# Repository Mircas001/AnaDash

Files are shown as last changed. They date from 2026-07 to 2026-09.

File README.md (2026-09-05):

# AnaDash - Resource monitor + macropad 
**THIS IS WIP! NOT TESTED YET!**
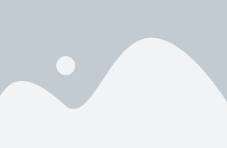
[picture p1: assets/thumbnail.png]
Thumbnail


This is an resource monitor for your PC, also featuring an macropad, inspired by Alex Bailey's system monitor and Hack Club's hackpad program! It allows you to take a quick glance and see your system information, while keeping the screen free for anything you do!
This was made after watching Alex Bailey's very silly cpu monitor video!, I've been wanting to make it for 2 years now! I also added an hackpad after seeing the very helpful Hack Club Hackpad program's guides

## Features:
- 4x Analog Gauges showing CPU usage, CPU temperature, RAM usage and Swap usage, driven by an MCP4728 chip!
- 8x Cherry MX keys for any macro your heart wishes!
- An LCD display that can show time, notifications and current song!
- An rotary encoder for changing your volume! Including a switch for mute!

## Case
AnaDash consists of embedded-rust-rp2040 parts, each one split into 
- An case, that supports it and holds it, also houses the raspberry, this part is split in two as it's too big to fit in most printers!
 
- An front plate, that you insert heatset inserts into and then screw the parts in, also split in two!
- An front case, which hides all the PCBs and wiring and gives a nice flush finish, split in two as well!
- An encoder, not split in two, with regular rectangular extruding parts for better grip while also keeping printability!

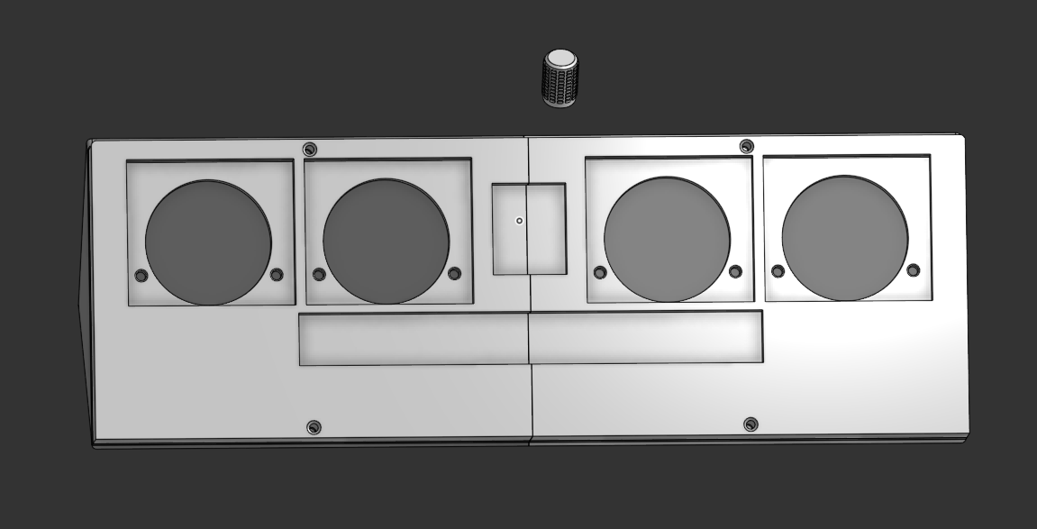
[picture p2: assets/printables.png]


Since the parts are split in two, you'll have to weld them, use an cheap soldering iron or preferentially an plastic welder for this job, since it can damage soldering tips. I can also help you make an version where both parts are one in case you want to print them as one part.

The design files are available [here](https://cad.onshape.com/documents/ea3d35dc7a38396ad80a61d7/w/835ea08936cef2d122cf7568/e/898c0cf3f941f1983e6f2559)

## PCB
This project was designed in KiCad, it uses a pair of 2 layer PCBs, the PCBs were split because the switches had to be at an angle while the pico had to sit straight.
For this to work, you must connect the following, all of the cables are JST-XH, as it features an locking mechanism.
You must make the following connections: (Pinouts are in left to right, when viewed from abovee!, GND will always be the rounded rectangle!) 
- DisplayConnector (BL, SCK, SDA, CS, RESET, CS, VCC, GND) - connect this to the matching pins on the display.
- LeftKeyConnector (Switch1, Switch2, Switch3, Switch4, GND) - The Input Board has matching connections!
- RightKeyConnector (Switch5, Switch6, Switch7, Switch8, GND) - The Input Board has matching connections!
- EncoderConnector (B, A, Switch, GND) - The Input Board has matching connections!

### Main PCB
This Board features the Pico, the DAC, the outputs for the ammeters, the display connector and the connections to the input board.            
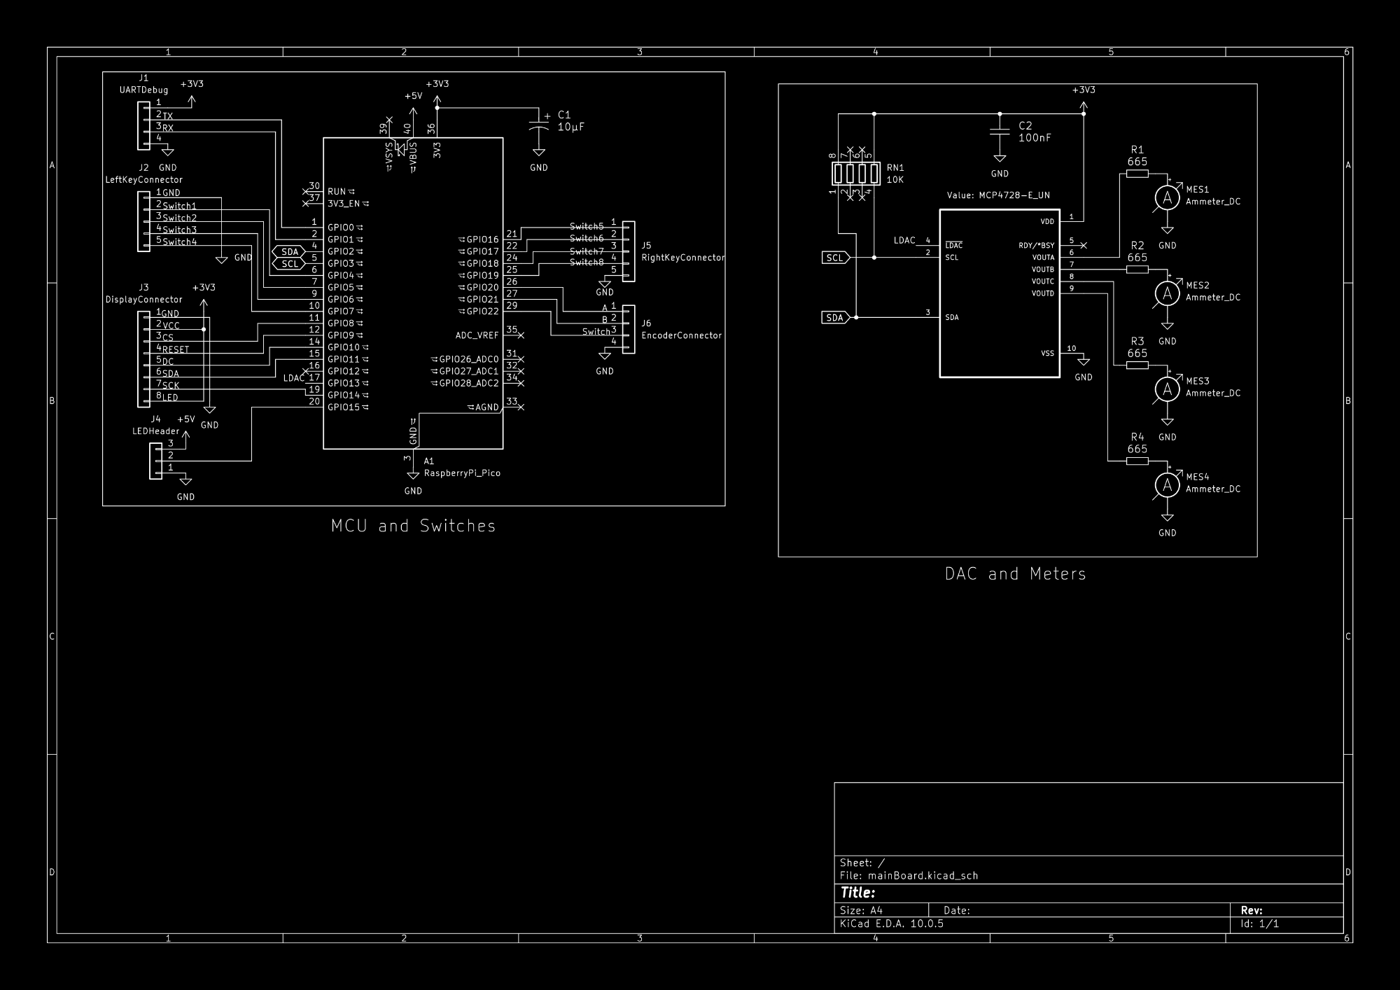
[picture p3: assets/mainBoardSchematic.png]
Schematic

[You can check out the PCB and schematic on KiCanvas!](https://kicanvas.org/?repo=https%3A%2F%2Fgithub.com%2FMircas001%2FAnaDash%2Ftree%2Fmain%2Fhardware%2FmainBoard)                                            
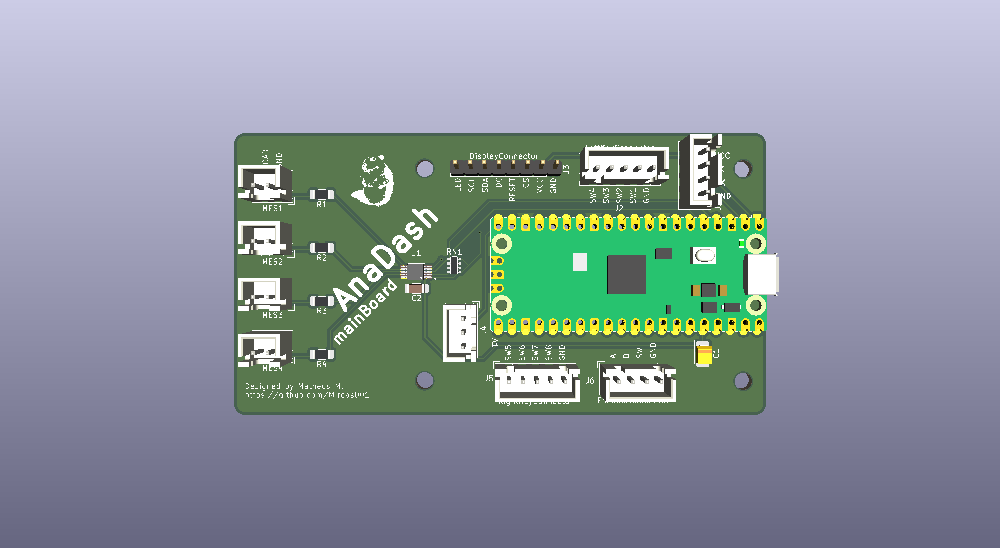
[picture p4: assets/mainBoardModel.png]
3D Model


### Input PCB
This PCB has all the keys and the encoder and serves to take inputs, it is angled together with the display and gauges at 45 degrees for ergonomics!                 
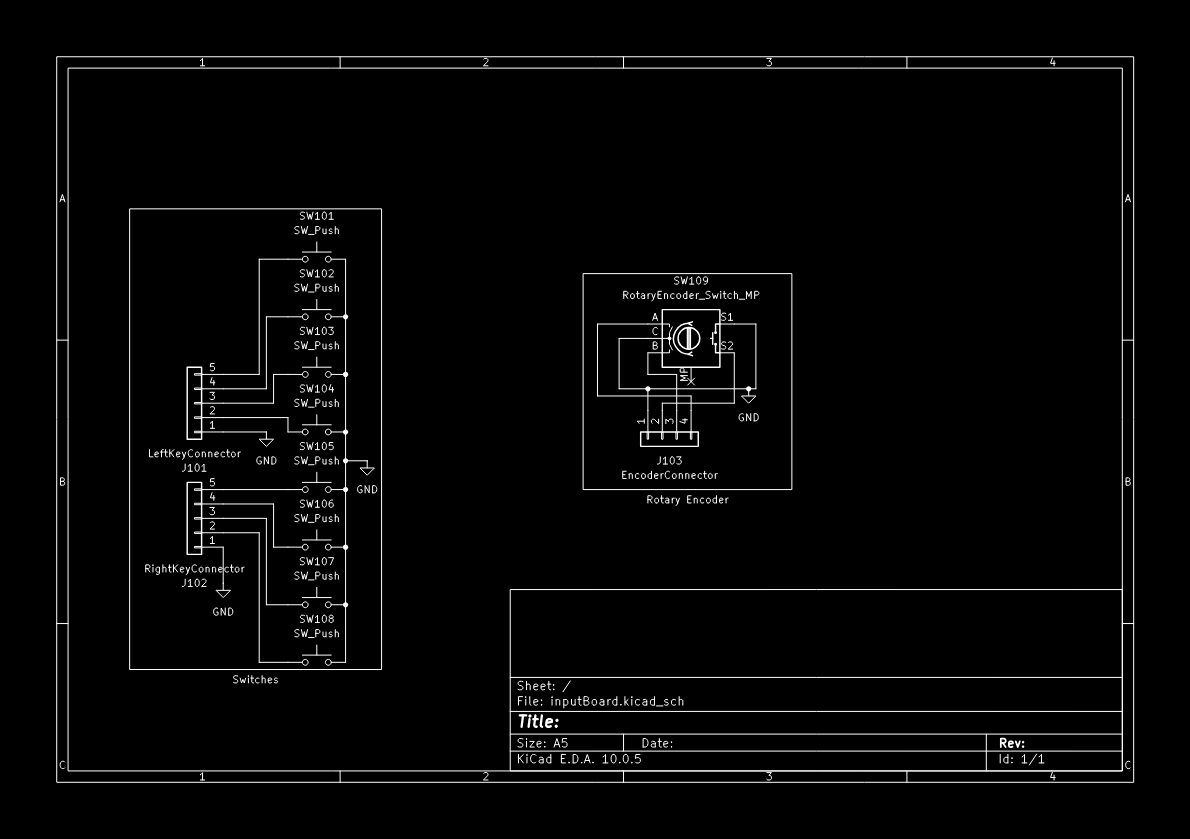
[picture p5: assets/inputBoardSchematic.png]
Schematic

[You can check out the PCB and schematic on KiCanvas!](https://kicanvas.org/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)                                         
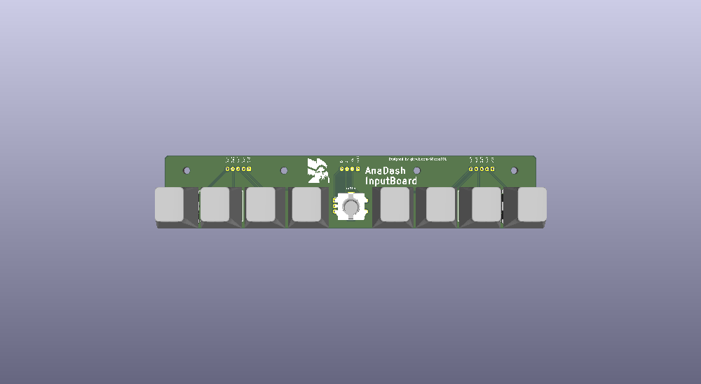
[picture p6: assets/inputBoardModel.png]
3D Model


## Software
The software has been done entirely in rust, it's memory safe, professional, and has great performance!

Before setting up the software, you'll need to install these programs!
- [rustup](https://rustup.rs) - this is the rust toolchain, and it's the recommended way to compile rust code!
- [probe-rs](https://probe.rs) - **ONLY IF** you are gonna upload via an **debug probe**.
- [picotool](https://github.com/raspberrypi/pico-sdk-tools/releases) - **ONLY IF** you are gonna upload via **USB**.
- [lm-sensors](https://github.com/lm-sensors/lm-sensors) - This provides the sensors the driver can read from! Make sure to set it up before!

It's consisted in 3 parts:
- Firmware: Runs the Pico!
- Driver: Gets the info from your PC!
- Shared library: This is so both firmware and hardware agree with each other!

### Firmware
This firmware supports the Raspberry Pi Pico 1!
There are two ways you can upload it to the pico:

#### Upload via debug probe
For this, you need to connect your debug probe to SWD port!
```bash
git clone https://github.com/Mircas001/AnaDash.git
cd AnaDash/software/firmware
cargo run --release
```

#### Upload via USB
For this, all you need to do is connect the Raspberry Pi Pico to your computer via USB, and run with the usb-deploy feature!
```bash
git clone https://github.com/Mircas001/AnaDash.git
cd AnaDash/software/firmware
cargo run -F usb-deploy --release 
```

### Drivers
This only supports Linux for now! But I can answer questions about the code to help anyone who wants to port it! It works as a systemd service that uses udev rules to start as soon as you plug it in!

#### PKGBUILD method
If you run Arch Linux or any other Arch Based distro, you can use this to install! For now you have to manually install the PKGBUILD, but it'll get uploaded to the AUR once it's done!
**This is the recommended method.**
```bash 
git clone https://github.com/Mircas001/anadash-driver.git
cd anadash-driver
makepkg -si
```

#### Compile it yourself
This is more complicated! But it should work!
1. Make sure you are in the dialout group to get serial perms!
```bash
sudo usermod -aG dialout $USER
```
2. Install all the files!
```bash
git clone https://github.com/Mircas001/AnaDash.git
cd AnaDash/software/driver
cargo build --release
sudo cp target/release/anadash-driver /usr/local/bin
sudo chmod 755 /usr/local/bin/anadash-driver 
sudo cp anadash-driver@.service /etc/systemd/system
sudo cp 99-anadash.rules /etc/udev/rules.d
```
3. Reload everything!
```bash 
sudo systemctl daemon-reload
sudo udevadm control --reload-rules
sudo udevadm trigger
```
It should work as soon as you plug in the device!

You're also always welcome to implement these steps in an package file, so other people with your distro have it easier!

### Troubleshooting the drivers
Since it's an systemd service, you can get the logs like this, replacing ```<serialport>``` with the device's serial port! Usually, it's ttyUSB0.
```bash
systemctl status anadash-driver@<serialport>.service
journalctl -u anadash-driver@<serialport>.service
```

## Assembly  
See [assembly.md](https://github.com/Mircas001/AnaDash/blob/main/ASSEMBLY.md)

## Usage
After installation of drivers, assembly, and flashing, the project SHOULD be plug and play. The macropad uses F13-F21, so to setup the macros, just use plug those keys in whatever software you want!  

## Debugging the device
There is an UART port at the main board for debugging!
Also, there are also some key combinations baked in the firmware:
- You can press the 1st key and the 8th key (the two outhermost keys) to reset the pico!
- You can press the 4th key and the 5th key (the two innermost keys) to go into DFU mode!

## Miscellaneous note
You will need to print the labels for the meters in A4 sticker paper, if you are an manufacturer, you should get it custom printed!                           
The labels are available here: [Labels](https://raw.githubusercontent.com/Mircas001/AnaDash/refs/heads/main/production/meterLabels.svg)

There is an LED header added to the PCB, however, I did not implement the code for it, it is there for future use! You are also free to repurpose it!

## BOM
| Designator | Qty |
| --- | --- |
| 1.77inch ST7735 Display | 1 |
| 85C1 Ammeter 5mA | 4 |
| FIXME SCREWS | 1 |
| M3 X 4.2 X L4.0 Brass Heatset Insert 100pcs | 1 |
| M2 X 3.2 X L4.0 Brass Heatset Insert 100pcs | 1 |
| Countersunk M3x8mm screw | 12  |
| Countersunk M3x20mm screw | 4 |
| Panhead M2x8mm screw | 4 |
| Panhead M3x8mm screw | 4 |
| Cherry MX Compatible Switches 10pcs | 8 |
| XDA2 1U Keycaps 10pcs | 1 |
| EC11 Rotary Encoder 20mm with Switch | 1 |
| JST-XH Kit | 1 |
| Raspberry Pi Pico | 1 |
| MCP4728-E | 1 |
| 10uF Tantalum Capacitor 1206 | 1 |
| 100nF Ceramic Capacitor 1206 | 1 |
| 10KΩ 4x0603 Concave Resistor Network | 1 |
| 665Ω Resistor | 4 |
| Main Board at JLCPCB  (PCBA) | 1 | 
| Input board at JLCPCB | 1 |
| 3D Printed parts | 7 | 

Details, such as aliexpress links, LCSC part numbers and cost (as of June 2026) are available here: [BOM](https://github.com/Mircas001/AnaDash/blob/main/production/BOM.csv)

It is strongly recommended

You can also get the JLCPCB BOM for the main board (in case you want to get PCBA) here: [BOM](https://github.com/Mircas001/AnaDash/blob/main/production/mainBoard/jlcpcb_bom.csv)

However, if you do get PCBA, it's recommended to only request the soldering of SMD components, as it's cheaper this way! Also, the 665ohm resistors need to be manually filled in, apparently they're so new there's not even a footprint for it! But I believe this issue will go away with time.         

The input board does not feature an JLCPCB BOM for PCBA because they do not have the parts for it! However, I have left the netlist and positions there in case you have an pick and place machine, but official support for assembling it this way is NOT provided! It's recommended to hand solder instead! Only THD components are used there.

## Software used:
This project was designed in:
- [KiCad for the PCBs!](https://www.kicad.org)
- [Visual Studio Code for the software!](https://code.visualstudio.com/)
- [Onshape for the 3D design!](https://onshape.com/)

## TODO List:
- [X] Design the main PCB 
- [X] Design the input PCB
- [X] Design the meters
- [X] Make the drivers
- [X] Make the driver into an actual driver
- [X] Make the firmware
- [ ] Make the Case

## Credits
- [Lex Bailey, for giving me the inspiration to start this project a few years ago, and for help with the meter labels](https://www.youtube.com/watch?v=4J-DTbZlJ5I)
- [Hack Club Macondo program, for the funding](https://macondo.hackclub.com/)
- [OrpheusPad, for serving as reference as to how should the git repo and README look like](https://github.com/qcoral/orpheuspad/tree/main)
- [HackPad program, which, despite not participating in it, guided me through PCB design](https://hackpad.hackclub.com/)
- [CarlKCarlK's clock project which I'm using as inspiration for parts of the codecode](https://github.com/CarlKCarlK/clock)
- [Siliconwit's guide on embassy-usb](https://siliconwit.com/education/embedded-rust-rp2040/usb-device-embassy/)

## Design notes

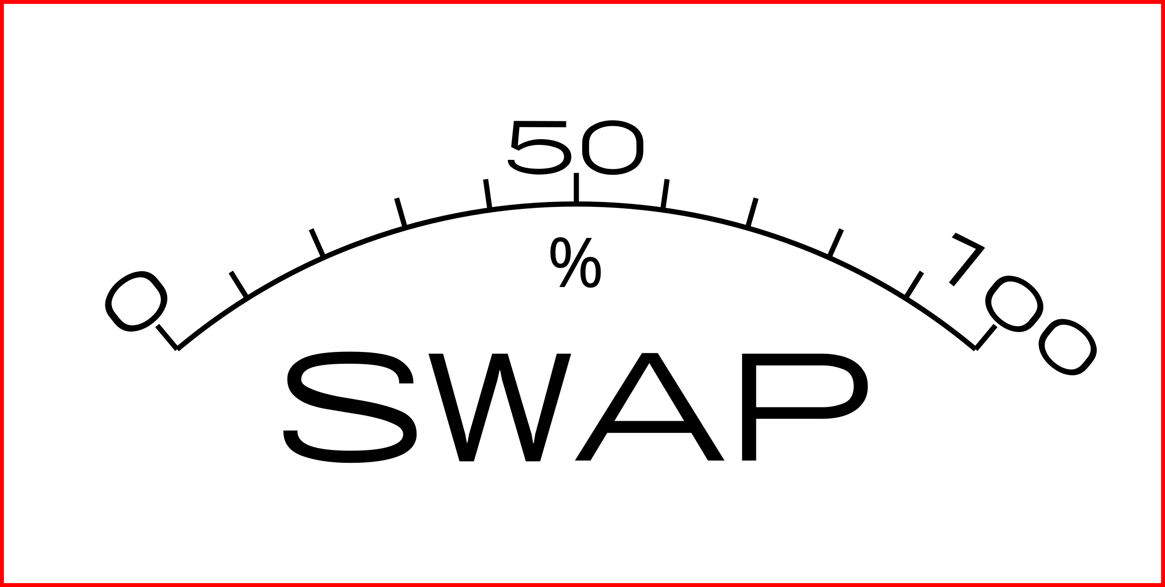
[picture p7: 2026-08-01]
hardware/case/assets/meterLabels_g7.png

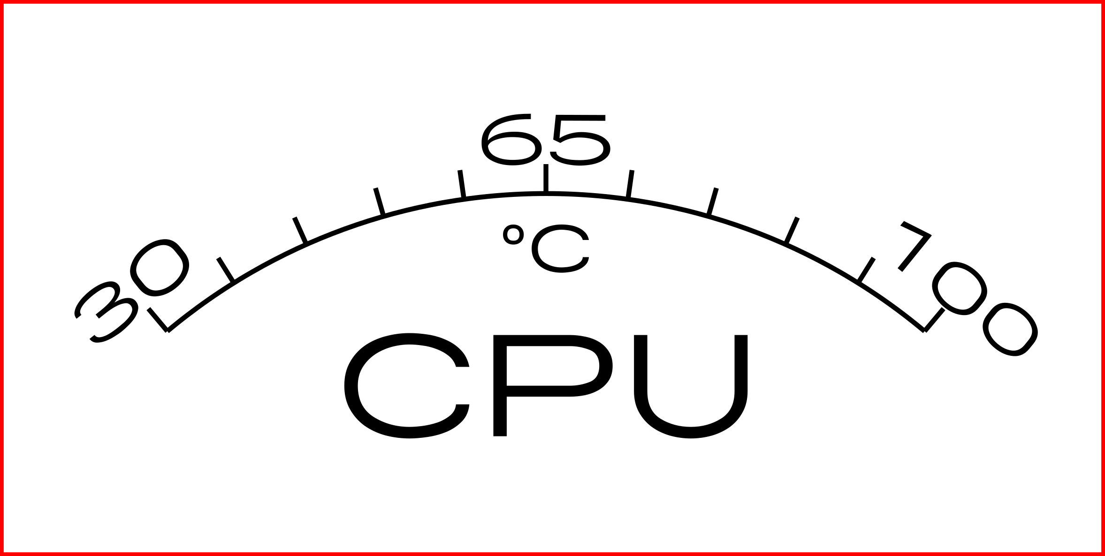
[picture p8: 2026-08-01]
hardware/case/assets/meterLabels_g4.png

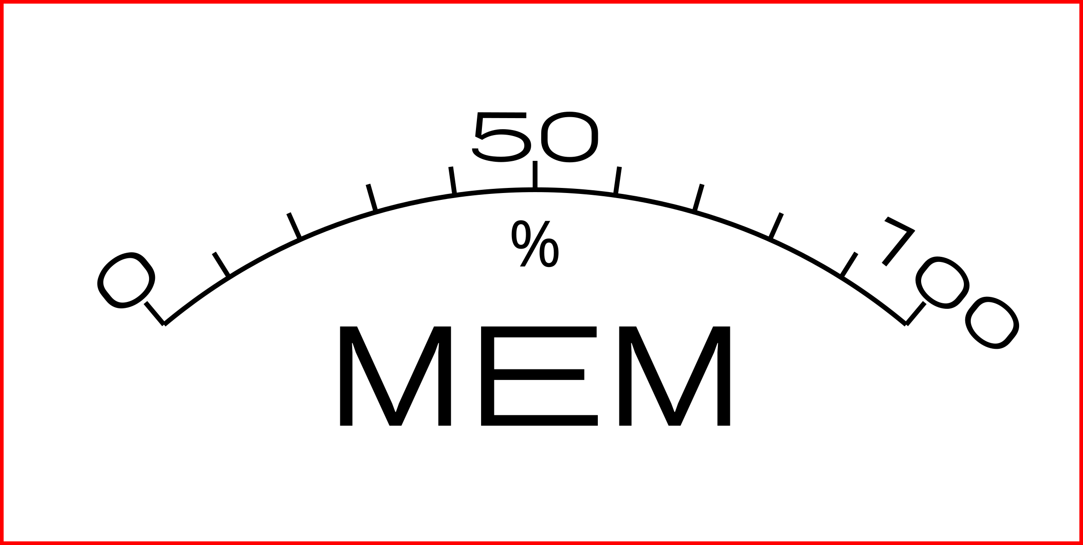
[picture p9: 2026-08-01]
hardware/case/assets/meterLabels_g2.png

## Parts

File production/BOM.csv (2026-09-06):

Designator | Qty | SMD/THT? | PCB | LCSC Part # | AliExpress Link | Price (Aliexpress Old User) | Price (Aliexpress New User)
1.77inch ST7735 Display | 1 | N/A | None | C5329585 | https://pt.aliexpress.com/item/1005003112573376.html | 2.63 | 1.60
85C1 Ammeter 5mA | 4 | N/A | None | - | https://pt.aliexpress.com/item/1005005650153387.html | 14.40 | 14.88
M3 X 4.2 X L4.0 Brass Heatset Insert 100pcs | 1 | N/A | None | - | https://pt.aliexpress.com/item/1005006838108683.html | 1.38 | 3.31
M2 X 3.2 X L4.0 Brass Heatset Insert 100pcs | 1 | N/A | None | - | https://pt.aliexpress.com/item/1005006838108683.html | 1.26 | 3.49
Countersunk Screw set M3 | 1 | N/A | None | - | https://pt.aliexpress.com/item/1005011580506515.html | 7.46 | 6.25
Countersunk Screw Set M2 | 4 | N/A | None | - | https://pt.aliexpress.com/item/1005007278965396.html | 4.77 | 3.61
Cherry MX Compatible Switches 10pcs | 1 | THT | inputBoard | - | https://pt.aliexpress.com/item/1005008948799927.html | 5.69 | 1.26
XDA2 1U Keycaps 10pcs | 1 | N/A | inputBoard | - | https://pt.aliexpress.com/item/1005006910173774.html | 2.97 | 1.27
EC11 Rotary Encoder 20mm with Switch | 1 | THT | inputBoard | C370986 | https://pt.aliexpress.com/item/1005007644083514.html | 2.97 | 1.27
JST-XH Kit | 1 | THT | mainBoard, inputBoard | - | https://pt.aliexpress.com/item/1005010377807416.html | 11.65 | 4.45
Raspberry Pi Pico | 1 | THT | mainBoard | C42924268 | https://pt.aliexpress.com/item/1005008948799927.html | 3.49 | 3.49
MCP4728-E | 1 | SMD | mainBoard | C108207 | - | 2.42 | 2.42
10uF Tantalum Capacitor 1206 | 1 | SMD | mainBoard | C7171 | https://pt.aliexpress.com/item/1005012317096366.html | 0.3772 | 0.3772
100nF Ceramic Capacitor 1206 | 1 | SMD | mainBoard | C24497 | https://pt.aliexpress.com/item/1005010653487250.html | 0.0498 | 0.0498
10KΩ 4x0603 Concave Resistor Network | 1 | SMD | mainBoard | C29718 | https://pt.aliexpress.com/item/1005004301411185.html | 0.0144 | 0.0144
665Ω Resistor | 4 | SMD | mainBoard | C54532953 | https://pt.aliexpress.com/item/1005005604946383.html | 0.0480 | 0.0480
Main Board at JLCPCB | 1 | N/A | None | - | - | 2 | 2
Main Board PCBA fees | 1 | N/A | None | - | - | 18.28 | 18.28
Input Board at JLCPCB | 1 | N/A | None | - | - | 6.90 | 6.90
3D printed parts | 400g | N/A | None | - | - | 20 | 20
Final Cost |  |  |  |  |  | 108.76 | 94.97

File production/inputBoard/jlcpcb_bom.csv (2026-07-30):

Designator | Footprint | Quantity | Value | LCSC Part #
J101 | JST_XH_B5B-XH-A_1x05_P2.50mm_Vertical | 1 | LeftKeyConnector | C157991
J102 | JST_XH_B5B-XH-A_1x05_P2.50mm_Vertical | 1 | RightKeyConnector | C157991
J103 | JST_XH_B4B-XH-A_1x04_P2.50mm_Vertical | 1 | EncoderConnector | C144395
SW101, SW102, SW103, SW104, SW105, SW106, SW107, SW108 | SW_Cherry_MX_1.00u_PCB | 8 | SW_Push | N/A
SW109 | RotaryEncoder_Alps_EC11E-Switch_Vertical_H20mm | 1 | RotaryEncoder_Switch_MP | C370986

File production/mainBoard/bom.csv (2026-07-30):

Designator | Footprint | Quantity | Value | LCSC Part #
A1 | RaspberryPi_Pico_Common_Unspecified | 1 | RaspberryPi_Pico | C42924268
C1 | CP_EIA-3528-15_AVX-H_HandSolder | 1 | 10µF | C7171
C2 | 1206 | 1 | 100nF | C24497
J1 | JST_XH_B4B-XH-A_1x04_P2.50mm_Vertical | 1 | UARTDebug | C144395
J2 | JST_XH_B5B-XH-A_1x05_P2.50mm_Vertical | 1 | LeftKeyConnector | C157991
J3 | PinHeader_1x08_P2.54mm_Vertical | 1 | DisplayConnector | C492407
J4 | JST_XH_B3B-XH-A_1x03_P2.50mm_Vertical | 1 | LEDHeader | C144394
J5 | JST_XH_B5B-XH-A_1x05_P2.50mm_Vertical | 1 | RightKeyConnector | C157991
J6 | JST_XH_B4B-XH-A_1x04_P2.50mm_Vertical | 1 | EncoderConnector | C144395
MES1, MES2, MES3, MES4 | JST_XH_B2B-XH-A_1x02_P2.50mm_Vertical | 4 | Ammeter_DC | C158012
R1, R2, R3, R4 | 1206 | 4 | 665 | C54532953
RN1 | R_Array_Concave_4x0603 | 1 | 10K | C29718
U1 | SOP50P490X110-10N | 1 | MCP4728-E_UN | C108207

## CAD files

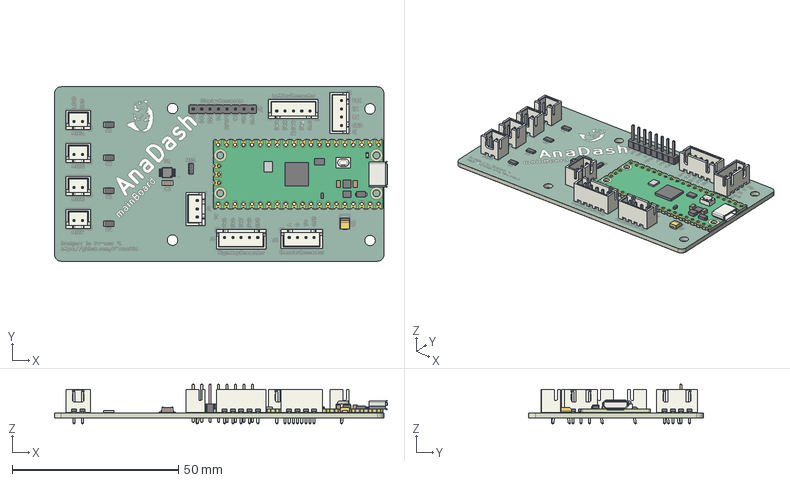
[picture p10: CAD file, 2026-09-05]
hardware/case/assets/mainBoard.step
100.2 x 52.5 x 11.9 mm
C_1206_3216Metric
R_Array_Concave_4x0603
JST_B4B_XH_A x 2
JST_B2B_XH_A x 4
MIC3232YMM
JST_B3B_XH_A
RaspberryPi_Pico_Module_KiCad
R_1206_3216Metric x 4
JST_B5B_XH_A x 2
PinHeader_1x08_P254mm_Vertical
CP_EIA_3528_15_AVX_H
mainBoard_silkscreen
mainBoard_soldermask x 2
mainBoard_PCB

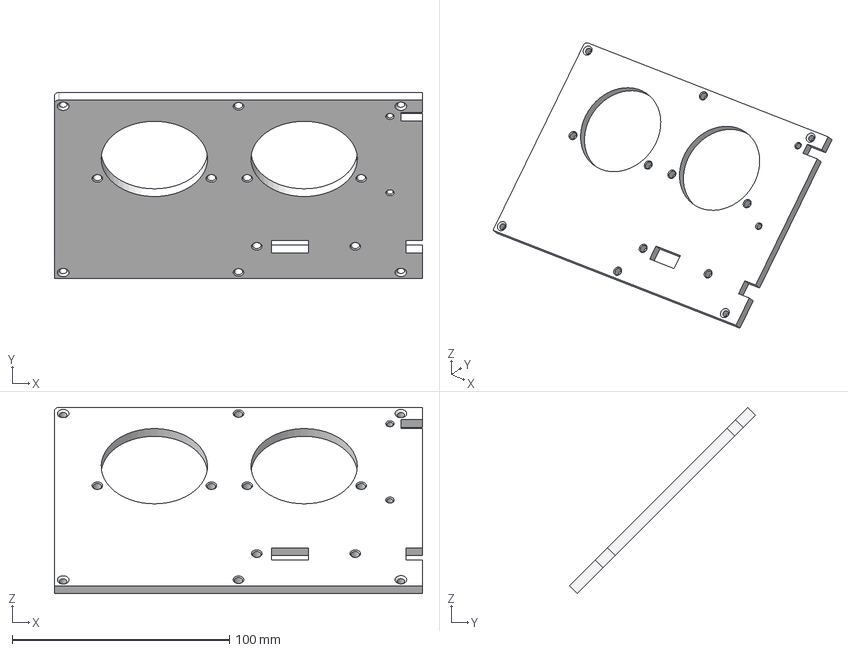
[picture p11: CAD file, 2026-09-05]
hardware/case/anaDash Printables - leftPlate.step
169.5 x 85.7 x 85.7 mm

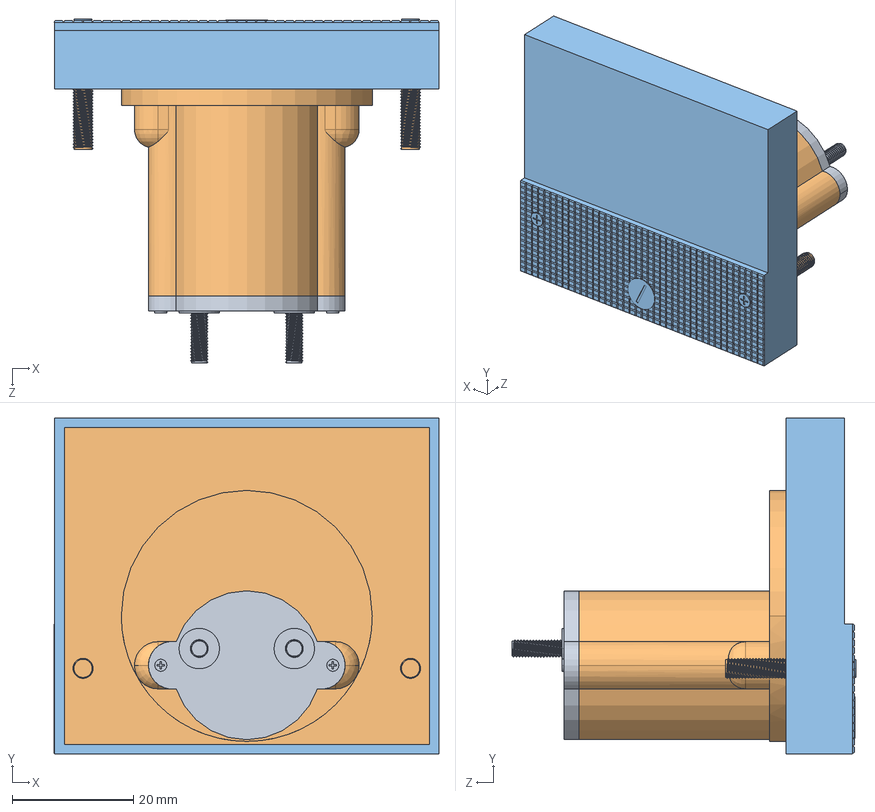
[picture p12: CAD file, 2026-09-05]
hardware/case/assets/Analog Current Meter 30mA.step
63.6 x 55.5 x 56.9 mm
Part3^Assem3
Part4^Assem3

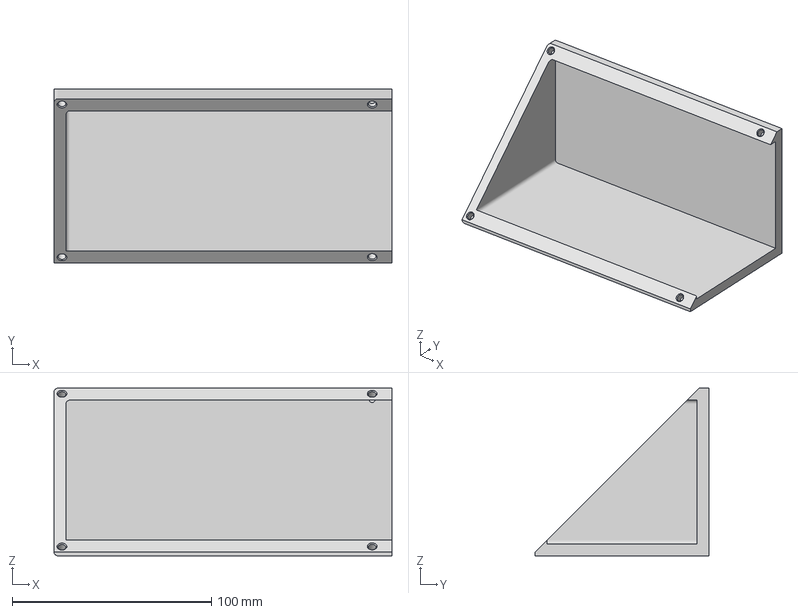
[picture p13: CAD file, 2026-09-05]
production/printables/separate/anaDash Printables - leftCase.3mf
169.5 x 87.0 x 84.1 mm

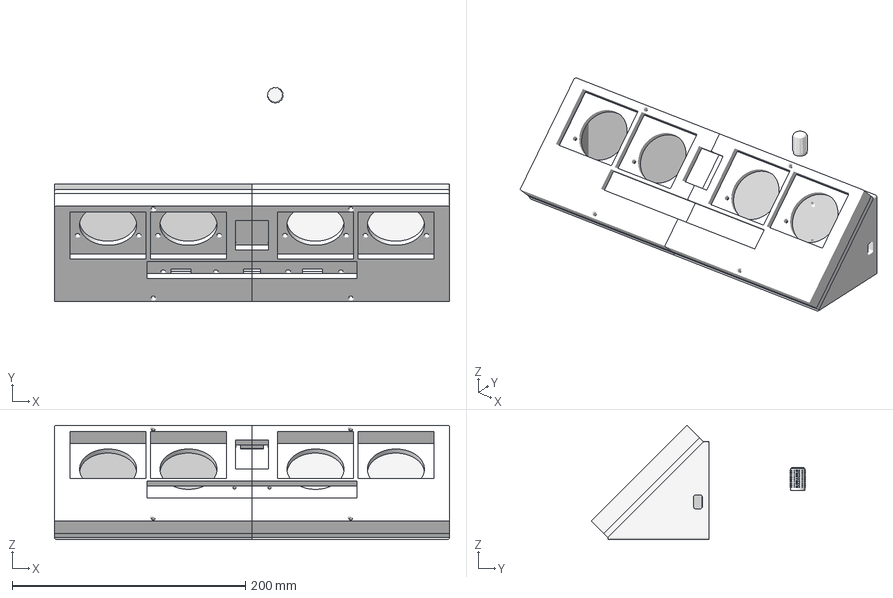
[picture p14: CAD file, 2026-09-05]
production/printables/sole/anaDash Printables.3mf
339.0 x 183.9 x 98.3 mm
rightFront
leftFront
leftCase
encoder
rightPlate
rightCase
leftPlate

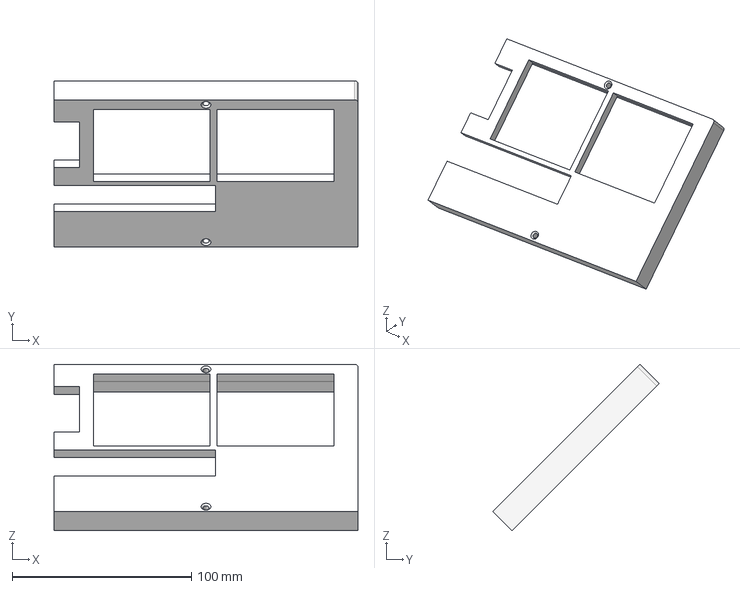
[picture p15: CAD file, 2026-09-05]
hardware/case/anaDash Printables - rightFront.step
169.5 x 92.8 x 92.8 mm

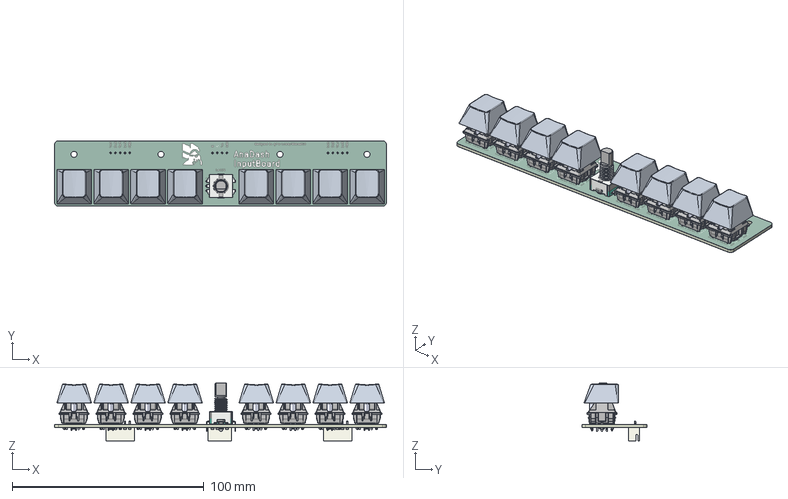
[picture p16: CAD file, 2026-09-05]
hardware/case/assets/inputBoard.step
173.0 x 34.0 x 30.1 mm
MX Öá °´¼ü¡ä_¨¹___¡§1 x 8
MX ס סͥ¨¢¨¬_¡§¡顧__ x 8
MXס ϞñLEDLEDLED x 8
MXÖá ÖáÌå µ×²¿ ¦Ì¡Á2__Ä¬ÈÏ_¨¢2____¨¨_ x 8
֫½ğ__Ĭɏ__¨¨_ x 8
r1_100 x 8
ѽת±ძǷ
JST_B5B_XH_A x 2
JST_B4B_XH_A
inputBoard-unsaved-export-LbCqLe_silkscreen x 2
inputBoard-unsaved-export-LbCqLe_soldermask x 2
inputBoard-unsaved-export-LbCqLe_PCB

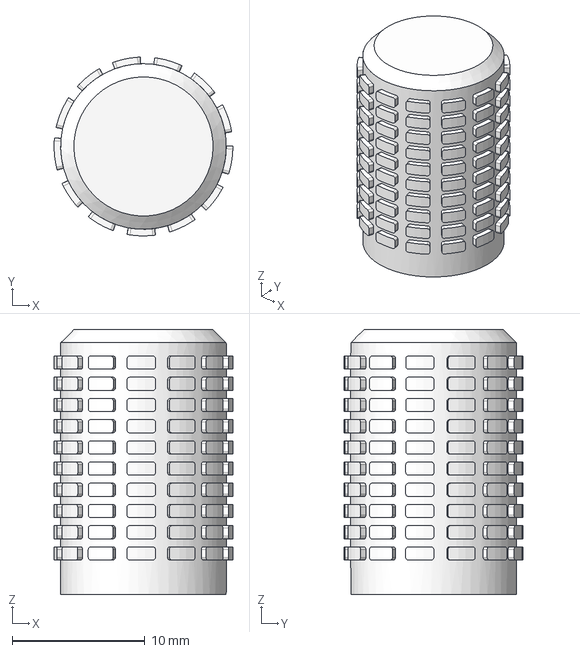
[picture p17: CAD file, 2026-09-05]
hardware/case/anaDash Printables - encoder.step
13.5 x 13.5 x 20.0 mm

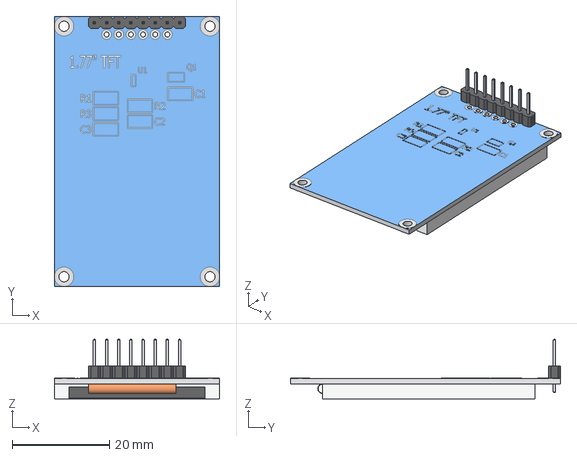
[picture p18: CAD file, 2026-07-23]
hardware/case/assets/1e77-TFT-160x128.stp
34.0 x 55.5 x 12.3 mm

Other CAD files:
production/printables/separate/anaDash Printables - rightFront.3mf
hardware/case/anaDash Printables - leftCase.step
production/printables/separate/anaDash Printables - leftPlate.3mf
production/printables/separate/anaDash Printables - leftFront.3mf
hardware/case/anaDash Printables - rightCase.step
production/printables/separate/anaDash Printables - rightPlate.3mf
hardware/case/anaDash Printables - rightPlate.step
production/printables/separate/anaDash Printables - encoder.3mf
hardware/case/anaDash Printables - leftFront.step
production/printables/separate/anaDash Printables - rightCase.3mf

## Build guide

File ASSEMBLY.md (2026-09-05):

## Items:
You should have
### PCB:
- 1x Main Board Board PCB (already soldered)

- 1x Input Board PCB (already soldered)

### Printables
- 1x Left Case 

- 1x Right Case 

- 1x Left Back Plate

- 1x Right Back Plate 

- 1x Left Front Plate

- 1x Right Front Plate

### Miscellaneous:
- 1x Meter Labels Sticker paper

- 4x 85C1 ammeters at 5mA

- 4x Panhead M2x8mm screws
- 8x Panhead M3x8mm screws
- 8x Countersunk M3x8mm screws 
- 4x Countersunk M3x20mm screws
- 4x M2 X 3.2 X L4.0 Brass Heatset Insert 
- 20x M3 X 4.2 X L4.0 Brass Heatset Insert

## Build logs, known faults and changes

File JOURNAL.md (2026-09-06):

---
title : "AnaDash"
author: "Mircas001"
description: "An cool looking dashboard for your PC! Features 4 analog meters for resources, 8 macro keys and even a LCD screen!"
created_at : "June26"
---

## September 5 - Final adjustments

Here's the final adjustments I need to make today:
1. Make the assembly.md 
2. Add the final files
3. Add final stuff to BOM.csv

For some reason, I begun with no 2, but that was good because I realized I used the wrong unit in the STL printable files, and then I remembered 3mf exists! So I used that instead, because, well, it's better, and all slicers support it! I also added the final of the assembled .STEP, individual step files for the printables, etc etc. 


And it will run us around 20$ to get all parts printed! 
I then started work on the BOM, which took a while, and I realized our silkscreen was obscuring one of the pin labels, so I fixed that! I did not update the step models tho, as the labels are not even carried thru.
Anyways, updating the bom took 30 mins because JLCPCB ordering is a bit hard, but I got it working, yay
I then realized the project was expensive and did the max optimization I could on the BOM, anyways this whole ordeal took 40 minutes in the end, yayy :D


This leaves me with the final boss: Assembly.md, sonnnn

**Total time spent: 40mins + hackatime time**

## September 5 - Today's the day I finally get this done!

So, you read the title, and here's the battleplan:
1. Add inputboard.step to onshape, and add all the design constrains and what not
2. Export all the files
3. Make the ASSEMBLY.md 
4. Go to sleep and submit tomorrow!

So I begun by putting the inputboard assembly, all went well, except for me struggling to figure out fastened mate, but I got it to work. But I realized that 
1. There was a family of abandoned boards living inside the thing 


That was fixed and now it's all okay:


2. The encoder lost the hole


This was caused by an extrude feature being deleted, I fixed it now:


Next, was going back and finally finishing the concentric circles, and at last: the finished 3d printed parts:


Then, I went back to the assembly and updated the references, and the screws:


And to finish it all off, I updated the BOM, and finally, we got this beautiful result:
https://cdn.hackclub.com/01a0731a-1d84-78eb-8455-47a4b0e457ed/image.png

I still need to figure out how to render, but I'm happy for now, so, next step of this project will be writing an assembly.md, which will be the next devlog! Yes I know I wrote that I would do it in this one, but I might as well split!

**Total time spent: 1h15min**

## September 4 - Devlog 37.2 - Time to fix this

I did get the feedback on the 31st, but I've been procastinating since, but alas, here is the peer review feedback:

Anyways, so, I begin by deleting every asset related to the PCB, why? Because that way, I'm forced to update it, and I dont leave an outdated mess!
So, I deleted everything in onshape, I hope i can fix it later...
Here's the before:

Well, tbh, they kinda face outward and are good enough, so, I'm not rotating them, but I'll do the rest!
Anyways, corners rounded, and I also added more silkscreen! here's the result!

after, it was a matter of exporting step files and fabrication!
Anyways, the inputboard was a bit easier, except for the fact I had forgotten an trace in the past submission, and i forgot to take a screenshot, I then also added some silkscreen to it!
Before:

After:

So, by now I have spent around 30 mins of my life, and the project has 95h and 53 mins, this is important because I'm logging it use onshape editor hackatime extension! So time to workk in the 3d design.

Update on 3D design: I screwed up importing the mainboard step, the silkscreen did not turn out good, but that's okay because I just deleted the bad part! It's silkscreen, won't affect me

Anyways, putting fastened mates was somewhat ok, untill I realized the right case was gone, but ok, it'll work. More stuff has disappeared, uhhh, I trust the thing. I then realized that it was missing an hole for the JST  spent over like, 15 mins trying to tweak the measurements until it worked!
During this, I got distracted by assembly.md, so I finished it
Andd my left front plate is gone, just like the right case:


Anyways, i had to extrude the left front plate again, and it came back I forgot, and itt works


Anddd the assembly wont update?????????????? whattttttttttttttttttttttttttt
I figured it out, I returned the assembly to an previous working started
And something I suspected happened, the context from the previous models would not work, oh well, I'm deleting itt
Well, I did not delete it but I can once again select it for some reason, nothing makes sense what
And I realized my screws were'nt placed right, yayyyy. Basically, they were UNALIGNED, A LOTTT.
Anyways, I did end up like, aligning it, but weirdly enough, it did not change it, and to mye eyes it then ended up unaligned again, so after 3 rounds of aligning I hope I fixed it. Which I did, due to the line tool showing it's aligned:


It's also important to note that since the third alignment, it's been a whole new day, but I'll continue working on the next devlog!

**Total time spent:2h**

## August 30 - Devlog 37.1 Time to fix this



Woops, I didnt fix it enough.


Okay, this one I'm asking forge help, however
Next:


Fair enough, I fixed it nowwwww, I hope it werks



Uhhh, the BOM.CSV needed help, that's for sure. Also forgot the STEP files, so that's fixed



Sent it for sanity check, awaiting reply, see y'all tomorrow

**Total Time Spent:20mins**

# August 29 - Devlog 37 Project Returned again, for a dumb mistake
Well, I saw this but I shosuld've known better, but the README is very vague, and it was an embarassingly simple fix, like a 5 minute fix, anyways, I'm resubmitting it, RIPPPP. Also added BOM, so yeah, there we go!


Sent it for sanity check, awaiting reply, see y'all tomorrow

**Total Time Spent:20mins**

# August 29 - Devlog 37 Project Returned again, for a dumb mistake
Well, I saw this but I shosuld've known better, but the README is very vague, and it was an embarassingly simple fix, like a 5 minute fix, anyways, I'm resubmitting it, RIPPPP. Also added BOM, so yeah, there we go!

**Total Time Spent:7mins**

# August 18 - Devlog 36 - Not final devlog, atleast I hope that's the end of design
Well, I needed schematic picture on the README.md, so, I have readded that, so simple, really, I didn't bother tracking it with Lapse, so yeah, that's done. I'm proud that it only needed this, expected 500 complaints, impostor syndrome ig! Also, the inputBoard schematic is now A5, since it's so smol. Oh yeah, I accidentally placed a PNG link to an SVG file, congrations to me ig. Anddd I used an svg not covering everything, tried again, still won't print, what? 

Oh, just print to pdf and export it using pdf to png tool. Anyways, I did that and the image turned out to have these horrible colors:

But it turns out it was because I was printing in color, so to fix this, I printed in black and white, and then inverted colors


**Total Time Spent:1h**

# August 13 - Devlog 35 - Final devlog 
Today, I finally ended it, I exported file, did a check up, and I believe I can finally upload it, damm, it just feels... so weird? Like, what, so disappointing, like, I can't understand, it's an different feeling... i haven't watched TV, in like 14 days working on this, yes I know this is not really dev but come on, let me talk

I thank everyone who guided me thru this, from the person who made the hack club instagram to the amazing people at the slack, I truly wouldn't have made this without you all. Also, I wish the opposite of an shoutout to customs people, y'all ruined my progress. Anyways, I hope the next one is an building devlog and not an fixing one.
Oh, after writing this, I was reminded that my README cad portion sucked, so that was fixed

**Total time spent:40min**

# August 12: Devlog 34 -  It's over, i'm free

I have finally finished this project, today I finished the diary, and I also polished up the project, making the screws self centered and whatnot, I accidentally screwed up the front plate in this process, so yeah, there's that, but it works!!!!!!!! That's what matters.
I'm so happy, i'm going to sleep, and upload tomorrow, in case any idea pops up in my head.
 

**Total time spent:1h20min**

# August 11: Devlog 33 - I FINISHED CAD

As you can see, the end product is here:

I finished the front plate, which hides all the ugly screws and PCBs, and makes for a nicer finished product, I probably need polish, and finally make an assembly.
The proccess was striaght forward, I made a rectangle which is an copy of the plate one, I added two screws, since this is cosmetic and doenst hold weight, an hole for screens and meters, and the keyboard, I also made this sit nice and flush by making it lower than the meters.

**Total Time Spent:1h56min**

# August 10: Devlog 32 -  I have finished the front plate

Mating the parts perfectly wanst too difficult, all I had to do is match corners, so yeah, that's done, but this inst the main focus.

I actually want to show what I finished, which i'm so so so proud, the circle idea was taken from Lex Bailey, shoutout to them, 

I just feel it's so professional omg, it looks like swiss cheese, but looking at the sketch will make it make more sense

As you can see, each hole is a screw, the big hole at the meters houses the thing the meter uses to put the gauge, the bunch of hashtags are variables, why? Those let me adjust stuff that's commonly repeatable, the reason i'm not doing an linear pattern is that I forgot those existed and I was win too deep, so that's why, but I did use it back at the encoder, ye, that's it

**Total Time Spent:2h54min**

# August 08: Devlog 31 - Screws have been figured out

Yes, I actually spent two hours placing screws, mainly because they were either sitting too high or they were upside down, BUT I FIXED IT! I had to do an offset at the mate connector, and voila, perfect flush screws.
I need to figure out how to mate these perfectly next.



**Total Time Spent:2h**

# August 06: Devlog 30 - No significant progress, but stuff has been figured out

Well, I wouldn't say I have made gargatuan progress, but stuff has advanced, and I figured out all 4 previous questions.

*1. How do I insert heatset insert?*
Well, you have to make .3-.4mm smaller than the outside diameter and add a chamfer to guide it in!


*2. How do I reference PCB design in sketch*
Onshape has a feature called context editing for this! It overlays the other parts in the assembly on top, and allows referencing them in sketches


*3 .How do I install the input board, angling the keys didn't look good so i'm placing them on top + i get to make it lighter?*
Since it's an triangle, only placing the 85C1 would have left no space for the mainboard pcb in the opposite cathetus/side. (cathetus, the smaller sides of the triangle, as opposed to the hypotenuse)

*4. This is huge, 256mm x 63mm x 80??mm, not confirmed yet, i'm worried. This is it, i'm so worried and confused and ahhhhhhhh*
Yeah, I WAS TIRED, anyways, just splitting it into two parts solved our issues, the only issue I have is the left part (pictured as the one doing nothing next to the one holding the PCB) is useless


**Total Time Spent:4h17min**

# August 03: Devlog 29 - So many complicated cad issues

As the title says, i've run into A LOT of cad issues, but i'll list em:
1. How do I insert heatset insert? 
2. How do I reference my pcb design in my sketch?
3. How do I install the input board, angling the keys didn't look good so i'm placing them on top + i get to make it lighter
4. This is huge, 256mm x 63mm x 80??mm, not confirmed yet, i'm worried.
This is it, i'm so worried and confused and ahhhhhhhh

5 minutes later, I have tought of a solution, previous designs stacked the meters side by side, but i'll do two blocks of 10mm of each, and make the size smaller


Oh yeah, I finished the encoder knob, and I hope this one is more 3d printer friendly


**Total Time Spent:1h30min**

# August 01: Devlog 28 - Encoder Knob is done AND I fixed the meters

As the name says, I have finished both the encoder knob and the meters, meters only took me half an hour, I had already gone thru all steps before and I didn't even need to do some, I had to get new a CAD Model and put the decal there, so that's done. Btw I'm actually really really proud of these meters! Looking at them just gives me satisfaction, idk why, so rewarding

Then I started to make the encoder knob, i'm not sure if this printable, and I maybe should consider getting an straight knurling instead, in fact, i'm actually gonna do that right now! Yeah, incredible idea. Anyways, knurling this took me an hour and half, because I had to figure out a bunch of new stuff. i'm not actually so proud of this, i don't know, it just looks evil and violent. Next step is redoing this


**Total Time Spent:3h10min**

# July 31: Devlog 27 - Onshape madnesss

So, apparently my pc is not strong enough to run fusion 360, so I went to onshape, so I first begun by designing an encoder knob, and 50 minutes later, voilá, I had one, and was quite happy...

But then I realized it needs to be in the same parts studio as my input board, so I deleted it with the intention of starting it over again. 
But, for some reason I do not know, I decided that I would put work on making the meters instead, and uhhh, it went well! Up until i spent 3hrs to realize the model I used was bogus, hooray, and I was so close too :((((. Anyways, i'm starting fresh, and i hope i get it all done by tomorrow


**Total Time Spent:4h15min**

# July 30: Devlog 26 - The whole project is nearly done except for CAD AHHHHHHHHH

Some final adjustments were made, stuff like the BOM, some bug fixing, and other polish.
As the title says, the whole project is nearly done, the pcb is done, the software is done, however, for some reason, FUSION 360 JUST DOENST WORK, WHY? I've spent the whole day trying to install this thing and it simply cannot function! WHY? WHY MUST IT WORK LIKE THIS? anyways, i hope it works now, but i'm in a standoff right now. 


**Total Time Spent:1h30min**

# July 28 Devlog 26 - Okay, NOW THE SOFTWARE IS FINISHED, AND THE PRODUCTION FILES 

I've added an LED header and decided to implement it, however, halfway thru, I got distracted, so I made all the production files, and they work well. Then, after an hour of coding, I have realized that adding LED support would be complicated and difficult, so i'm calling it off, and, instead, I'm just leaving the LED header there, empty, for the future


**Total time spent:1h30min**

# July 28: Devlog 25 - SOFTWARE IS DONE LETS GOOOOOO

I have finished software side of things, the final thing needed being a music player, I skipped the progress bar due to it being an hassle to implement, and I don't have much time. But, overall, it's finished, it should work. The biggest problem during this step was well, figuring out how do i make the icon for the player status, but the solution was implementing a custom struct as much as an hassle that was, anyways, everything works now, let's GOOOOOOOOOOOOOOOOO!
The next step I plan is adding an optional led strip header


**Total time spent:3h30min**

# July 27: Devlog 24 - I have finished the driver 

I stopped working on the firmware for the UI so I could work in an intermission for the driver, I begun by first making a PKGBUILD, but, after seeing tests being performed, I got sucked in a rabbit hole, spending over an hour writing benchmarks only to find out the library I'm using to perform benchmarks didn't support binaries, but that didn't stop me from writing a simple test that prints the system info to the terminal. I also rewrote the function that gets cpu temp to use an more universal approach using lm-sensors. 
After that 1h30m rendezvous I started making the PKGBUILD, like many other things in the project, it was a whole new world, however, after over an hour of work, it works and it compiles! It was very very rewarding.
Finally, to wrap it all up, I cleaned up most warnings, there's just one that throws an error when I try to fix it LOL.


**Total time spent:4h**

# July 27: Devlog 23 - Implementing the UI for my project

I begun writing the code for the display, only to realize my decision to not care about what pins I used would backfire, so, I had to rewire the schematic AND pcb, but it's all okay now. Also, learning this was tough, whole new world, spent over an hour just figuring out how to pass the embassy spi to the ST7735 driver.
After that, I begun by making the status bar, aka 
Anyways, after that, things went okay, I did have an hiccup when getting icons to show on the screen, because the library I initially used was garbage, or so I tought, atleast that's what I tought at the time, but after switching to a different library, I managed to get the notification icon.
Then, implementing the notification UI was a breeze, I had a hiccup because I had to learn linearlayout, but besides, that, it went okay.
Then, I implemented the music player and default screens, while the default screen went okay, the music player, which is where I am now, is a bit hard because I need to figure out how do I show progress, I initially tought of a bar, but i'm thinking of just using a string, tho that would be sad.
During that, I don't know how, but something told me that the previous library for icon (which was superior due to it having more icons) was working and that I was wrong, sure enough, the issue was me not implementing the feature for the icon I wanted to implement
I am now stopping this devlog because it got too big, but that's where i am now.


**Total time spent:4h30min**

# July 24: Devlog 22 - MCP4728 was hard, and I made the driver better

Let me first begin by saying, that this line:

```
    meters
        .fast_write(dash.cpu_load, dash.cpu_temp, dash.mem_used, dash.swap_used)
        .await
        .unwrap();
    hardware.ldac.set_high();
```

Kinda took me an hour to make, and 2 hours in ADHD sidetracking.
So, to get to this line, I had to remake the driver, not only because I was using computationally expensive floats, but because an u64 for an value between 0-4096 was wasteful of bytes. 
While on it, I sidetracked and decided to redo the way the driver interfaced with the USB device, because it felt quite unprofessional to just bake in the serial port.
So, I wrote this fancy function that gets the serial port via the VID and PID, and it looks something like this:

```

    let keyboard_port = match utils::get_serial_with_vid_pid(DEVICE_VID, DEVICE_PID) {
        Ok(port_info) => port_info,
        Err(e) => {
            panic!("Error getting serial port! {}", e.description);
        }
    };
    let mut keyboard_cdc =
        match tokio_serial::new(keyboard_port.port_name, 115200).open_native_async() {
            Ok(port) => port,
            Err(e) => panic!("Error opening serial port! {}", e),
        };

```
As you can see, it's now way more professional!
After that bit of sidetracking, I finally redid the types, and when I realized I would need an arduino style map functions, and that I was bored without internet, I rawdogged an library using the rustup documentation, not tracking the hours tho. You can get it via the crate "map-arduino", and it works with all data types, I'm proud of myself!
Finally, after all that work, I had to do the MCP4728, and that line in the start took a loong time, mainly because theer were 500 different I2C types and I didnt understand anything, but, at last, it works ;D



**Total time spent:2h8min**

# July 23: Devlog 21 - New UART Port, better drivers

I took a break from programming and decided to go back to PCB design, I replaced the screen pinout, and, more importantly, added an debug UART pin so you can get logging, while on it, I realized I would have to move a bunch of connectors! So i spent over an hour painfully rerouting, only to realize it broke more, I also had to rethink the pull up resistors because those had nowhere to go, anyways, thankfully everything's working now, so i'm happy. After that break, I decided that I would start the handler for incoming host messages, but, for some reason, which I dont know, I started doing the README??? anyways, the readme is very pretty and has instructions on how to compile now, so that's great ^^. Then, for some reason I decided to do the driver again?? I improved it, and it now gets the serial port using VID and PID, wayy better, it was just painful figuring out for the first time how to use results! And on a more unrelated note: If you noticed, yes, I'm purposefully delaying the CAD part because it's been hell whenever I tried it, fusion 360 simply won't run and I'm not sure if onshape is good for polishing, also I'm so scared of the deadline cuz I'm not sure if JLCPCB can get the parts here in time, the BOM is also scaring me, seems so complicated. 



**Total time spent:4h40min**

# July 21: Devlog 20 - CDC is done, so is the encoder

As the title says, I finished both of them and I'm very excited to move on to the next step which is driving the MCP4728 :D ! The rotary was tough because there's 700 hundred libraries, but I picked the one someone in youtube had used, as that's an good proof. The CDC was tough understanding the new concepts, but i'm proud it turned out ok! Anyways, can't wait for the UI part after the MCP4728, and I hope this project is shipped by sunday :D. 



**Total time spent:1h38min**
,
# July 20: Devlog 19 - I made it work :D

I have figured out that partial move issue! :D All I had to do was just stop trying exporting the peripherals object, so that's solved :D I have finished the part that sends the macro keys to the computer, and i'm really proud of how it turned out! I'm also proud of the solution I used to save up memory, which is an bool array made out of one u8 int! I save up 7 bytes, which is small, but you gotta remember our memory is constrained! I also implemented the encoder switch, and I've been making more use of consts! The next step will be implementing the CDC! 


**Total time spent:2h30min**

# July 20: Devlog 18 - I spent 5 hours developing the firmware only for it to be pain

I started developing the firmware, BUT IT'S SO HARD AND CONFUSING, while I had a bit of an whiplash when I started developing the driver, it was nothing compared to what I'm currently experiencing with the no_std embassy firmware. I don't really understand what I'm doing, I'm having to learn new concepts such as lifetimes and other stuff and it's so confusing and messy, it's making me crazy. To make matters worse, I was about to delete part of the firmware to start over but somehow the problem went away??????????? What??????????????? It doens't make sense, nothing should be working here, but somehow, it does, and that does not make sense Nevermind the error is back, it just wans't included in the commits, I have no idea, i'm tired. 




**Total time spent:5h**

# July 18: Devlog 17 - Driver's done

Well, this part was a bit different cause a bunch of new concepts came into play, but basically, to get data from the PC to the driver I had to use serialization and deserializaiton, basically it's like packaging a cake, and then taking it out of the packaging and eating it at home, yum. I also switched from std strings to heapless strings cause those are memory friendly, crucial for something like a embedded controller, it's basically C style char array. Anyways, I had to apply these and voila, it worked


**Total time spent:3h**

# July 18: Devlog 16 - Driver is nearly done

The rust driver is nearly done :D It gets the system information, it gets notification, gets mpris player information, and gets the time. It wanst easy, I spent a lot of time learning tokio, I also had to learn some concepts about parallelization, but i'm really happy with how it turned out :D I have been struggling with an creative block for some reason, idk, it just feels daunting to finish this. 


**Total time spent:2h30min**

# July 15: Devlog 15 -  I made the labels for the meters, but at what cost?

I have made the labels for the meters, at the cost of my sanity :( For context, the measurements and arch thing I am borrowing from Lex Bailey at Computing the Details, however, the rest I made from scratch. For the first 20 minutes, things went smoothly, and i added the label of what the meter measures, along with 50% and the unit it's measuring. But things did take a turn when adding the other 2 values. See how it's at an angle (because this is a needle meter), it was hell to align it with the text, I spent an hour of my life frustrating about how do I even do this, in the end, the solution I decided upon was just accepting defeat and making it roughly accurate, but it's quite an bummer 


**Total time spent:2h14min**

# July 14: Devlog 14 -  Labeling my connectors and rust code updates 

I have labeled the connectors on both PCBs! Why? Because I realized my README got confusing with the pinouts, and I realized it would be an struggle to connect everything based on a single markdown file. 


Another thing I did was divide my rust code. Why? Well, I realized it was going to get big, and to prevent 1000 line monster files I spun off the part of the code that gets sensor data into another file

Another thing: Right now, I have no idea about what should be the next step of the projecrt, and it's driving me nuts! I've also been struggling about what the BOM should look like.

**Total time spent:40min**

# July 13: Devlog 13 - We are now using the raw MCP4728 chip 

I have switched from the adafruit prebuilt DAC module to the raw MCP4728 chip, this way, I cut the cost of the DAC in about half. Since it was my first time doing a raw chip, it was pretty tough, and quite complicated to understand, took 2 hours of my life. But it works, it's a mess tho, but hey, I'm glad it works! It feels a bit wrong too, idk why, I might have to do a clean up. 




**Total time spent:5h57min**

# July 10: Devlog 12 - Switched displays :D 

I have switched displays, why? Well, I realized that having some constant UI on an OLED display will quickly lead to burn in, so that's a major change. I'm glad I haven't actually started designing the UI, so I didn't lose a bunch of time designing for a monochrome display.


**Total time spent:1h**

# July 10: Devlog 11 - Driver done yay

I rewrote the whole entire thing, and we finally have achieved drivers :D, reading the cpu load average, memory and swap were pretty easy, as I had already done it before, the only issue was reading the temperature, I did have to learn quite a bit, but it works, I also have added the time too! Now, it's not ready in any way, shape, or form, for now it just prints the data to console, but i'm overall really happy with the results! Next devlog I'm making firmware and finally moving on to the monster that's named 3d modeling, I did try it today, only for onshape to not be really good and fusion just refuses to run. Do note that this is just the beta firmware, I'll hold on the fancy features for now, and will only be adding them when I get to build it.


**Total time spent:3h 30m**

# July 09: Devlog 10 Driver madness

Today, I woke up feeling like doing the drivers, so that's what I at least tried to do...

However, I am struggling to find a library handling both cpu temperature and memory and it drove me insane!

I am probably going to have to accept defeat, and instead opt for getting memory and swap from sysinfo rust crate, and temperature from the hwmon or thermalzone files in Linux... 
By the way, yes, I did not work the past few days


**Total time spent:5h**

# July 05: Devlog 9 - Both PCB done

I have finished both PCBs :D It was pretty smooth actually, I haven't got it sanity checked yet, but, I'm actually surprised due to how smooth that went. The biggest issue was getting the 3d models just right, and also figuring out where to place stuff. Also, making sure both connectors were matched was sorta an issue. Also, I have begun writing the README, but, I'm struggling a bit with it. 



**Total time spent:1h**

# July 03: Devlog 8- The mainboard PCB is done, hooray :D 

Making the PCB was actually rather smooth. Now, I DID encounter some issues. But it was mainly with the 3D model of the DAC I had downloaded, but the fix for that was just making one myself with the Adafruit PCB Design files. I'm very very happy and proud of this work :D 



**Total time spent:3h**

# July 02: Devlog 7 - 41 ERC Errors

Basically, I went to check the ERC and I had 46 errors. Half of them were simply a lack of an not connected symbol 

However, the other half was just something else. What happened, was that the connectors were all specified as bidirectional pins, so, KiCad freaked out like i just put 120V on an I2C line So, I decided I should try making my own symbols manually
Horrible mistake

Kicad sent my library to outer space and I spent 20 minutes trying to find where did it go. Not only that, but I didnt even need to actually make a new symbol! I was using one connector library, and all I had to do was switch to the other! I hope I can start making the PCB now And if you're curious, the ammeter is our gauge, the thing we are gonna drive. 


**Total time spent:4h**

# July 01: Devlog 6 - Splitting PCBs

Basically, i HAD begun designing PCBs, keyword HAD. Now it took 90 minutes of my life for me to realize something: For context, you need to understand that the dashboard part of the project will be sitting at angle, for the sake of ergonomics. So, I quickly ran into an issue, which was that mounting an pico at an angle would make it hard for the USB cable later. I also ran into the issue that the PCB would be too big to fit in JLCPCB promotion of 5$ to get a PCB. So, after thinking, I decided the best course of action would be to split the design into two PCBs, now, I haven't started the PCB part, but I did start the schematic part. I also took this oppurtunity to make the schematics pretty. 



**Total time spent:2h**

# June30: Devlog 5 - I botched the CAD

Remember that cad from yesterday? Well, basically, I made an useless box. Why? Because I dont have a PCB to put there, and the measurements were wrong, so I'll have to redo the design. I'll explain it better the day I do the 3d design Second, I have re-added the rotary encoder switch, I also had to change the switches's pins because I realized routing the switches wire to the other side would be awkward. (You see, it would be 4 switches on one side and 4 on the other, so it's best to use that side's pins for the switch) Another improvement to the schematic today was the addition of test points and status LEDs for debugging. 



**Total time spent:1h5min**

# June29: Devlog 4 - I came back to the pico
 
Today, I realized going to the esp32 was a pretty dumb decision, because it doenst come with USB support natively (which I need for the macro keys), so I went back a few commits to the pico 

So I replaced the pico with the cheaper ESP32.
Also, I added a rotary encoder to go with the 8 macro keys, and a buzzer, for notification sounds


**Total time spent:1h15min**

# June27: Devlog 2, footprints and stuff 

Devlog 2
I have figured out how to do the footprint :d:

Basically, I figured out I was looking for exact precision, when not even the machines are that precise So what did I do then? Well, I still used Kicad's finest grid of 0.001mm, and i got the thru hole aligned with a precision of 0.0005mm, or an micrometer, which is perfect. 

Other stuff

I begun to wire the DAC and the meters, which is quite simple. You may notice this curious arrangement of 2 330ohm resistors in series, it's because they dont make 660ohm resistors 


**Total time spent:2h5min**

# June26: The beggining 

Today, i have started the development of AnaDash, this project aims to be a cool dashboard for your PC, featuring 4 analogue resource monitors, a few macro keys, and an OLED screen for showing whatever your heart desires! Today, I begun the project, then realized that i can't find the DAC breakout board online, so what i did? I decided to make my own footprint 

This was an horrible mistake
What I didn't realize, is that for some reason, the PCB adafruit provides is off-center, this is def an issue in my part during some part of the conversion process. Even on the finest grid, it's still of center, just why?]


**Total time spent:3h**

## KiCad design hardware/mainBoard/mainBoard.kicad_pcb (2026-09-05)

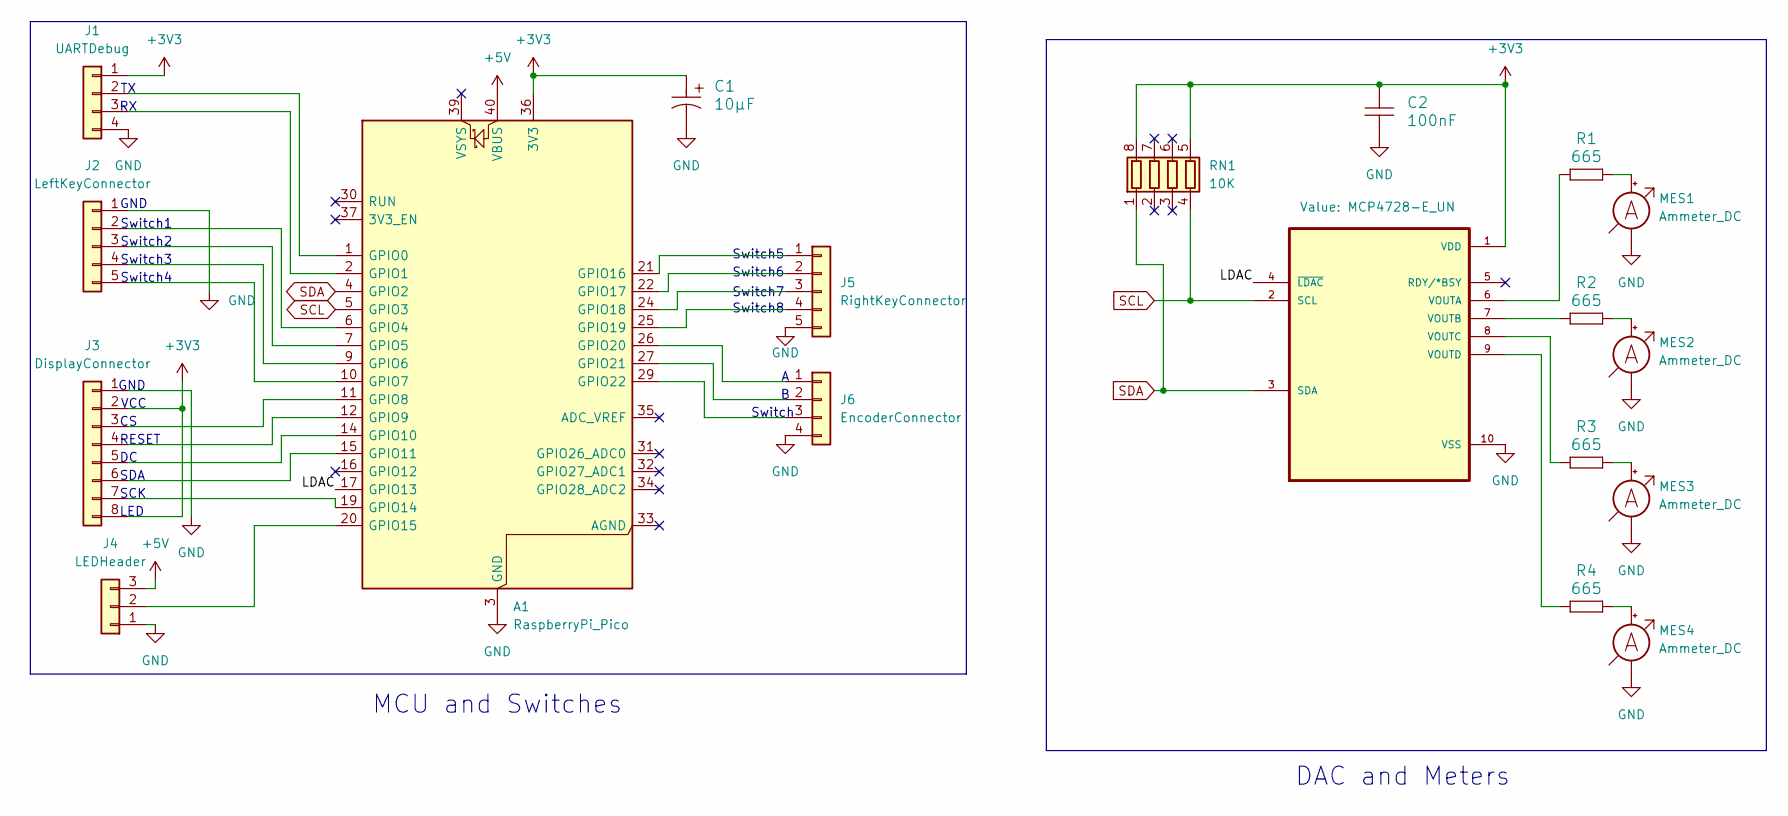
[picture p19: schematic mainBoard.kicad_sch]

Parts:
A1: RaspberryPi_Pico; RaspberryPi_Pico_Common_Unspecified; LCSC Part # C42924268
C1: 10µF; CP_EIA-3528-15_AVX-H_HandSolder; LCSC Part # C7171
C2: 100nF; C_1206_3216Metric_Pad1.33x1.80mm_HandSolder; LCSC Part # C24497
J1: UARTDebug; JST_XH_B4B-XH-A_1x04_P2.50mm_Vertical; LCSC Part # C144395
J2: LeftKeyConnector; JST_XH_B5B-XH-A_1x05_P2.50mm_Vertical; LCSC Part # C157991
J3: DisplayConnector; PinHeader_1x08_P2.54mm_Vertical; LCSC Part # C492407
J4: LEDHeader; JST_XH_B3B-XH-A_1x03_P2.50mm_Vertical; LCSC Part # C144394
J5: RightKeyConnector; JST_XH_B5B-XH-A_1x05_P2.50mm_Vertical; LCSC Part # C157991
J6: EncoderConnector; JST_XH_B4B-XH-A_1x04_P2.50mm_Vertical; LCSC Part # C144395
MES1, MES2, MES3, MES4: Ammeter_DC; JST_XH_B2B-XH-A_1x02_P2.50mm_Vertical; LCSC Part # C158012
R1, R2, R3, R4: 665; R_1206_3216Metric_Pad1.30x1.75mm_HandSolder; LCSC Part # C54532953
RN1: 10K; R_Array_Concave_4x0603; LCSC Part # C29718
U1: MCP4728-E_UN; SOP50P490X110-10N; LCSC Part # C108207

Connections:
+3V3: A1.36 (3V3), C1.1, C2.1, J1.1, J3.2, J3.8, RN1.5 (R4.2), RN1.8 (R1.2), U1.1 (VDD)
+5V: A1.40 (VBUS), J4.3
/LDAC: A1.17 (GPIO13), U1.4 (~LDAC)
GND: A1.3 (GND), A1.8 (GND), A1.13 (GND), A1.18 (GND), A1.23 (GND), A1.28 (GND), A1.38 (GND), C1.2, C2.2, J1.4, J2.1, J3.1, J4.1, J5.5, J6.4, MES1.1 (-), MES2.1 (-), MES3.1 (-), MES4.1 (-), U1.10 (VSS)
unnamed: A1.1 (GPIO0), J1.2
unnamed: A1.2 (GPIO1), J1.3
unnamed: A1.6 (GPIO4), J2.2
unnamed: A1.7 (GPIO5), J2.3
unnamed: A1.9 (GPIO6), J2.4
unnamed: A1.10 (GPIO7), J2.5
unnamed: A1.11 (GPIO8), J3.3
unnamed: A1.12 (GPIO9), J3.4
unnamed: A1.14 (GPIO10), J3.5
unnamed: A1.15 (GPIO11), J3.6
unnamed: A1.19 (GPIO14), J3.7
unnamed: A1.20 (GPIO15), J4.2
unnamed: A1.21 (GPIO16), J5.1
unnamed: A1.22 (GPIO17), J5.2
unnamed: A1.24 (GPIO18), J5.3
unnamed: A1.25 (GPIO19), J5.4
unnamed: A1.26 (GPIO20), J6.1
unnamed: A1.27 (GPIO21), J6.2
unnamed: A1.29 (GPIO22), J6.3
unnamed: MES1.2 (+), R1.2
unnamed: MES2.2 (+), R2.2
unnamed: MES3.2 (+), R3.2
unnamed: MES4.2 (+), R4.2
unnamed: R1.1, U1.6 (VOUTA)
unnamed: R2.1, U1.7 (VOUTB)
unnamed: R3.1, U1.8 (VOUTC)
unnamed: R4.1, U1.9 (VOUTD)
SCL: A1.5 (GPIO3), RN1.4 (R4.1), U1.2 (SCL)
SDA: A1.4 (GPIO2), RN1.1 (R1.1), U1.3 (SDA)

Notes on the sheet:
MCU and Switches
GND
Switch2
SCK
Switch
Switch1
DAC and Meters
Switch5
Switch7
GND
Switch6
Switch3
SDA
RESET
Switch8
Switch4
LED
VCC

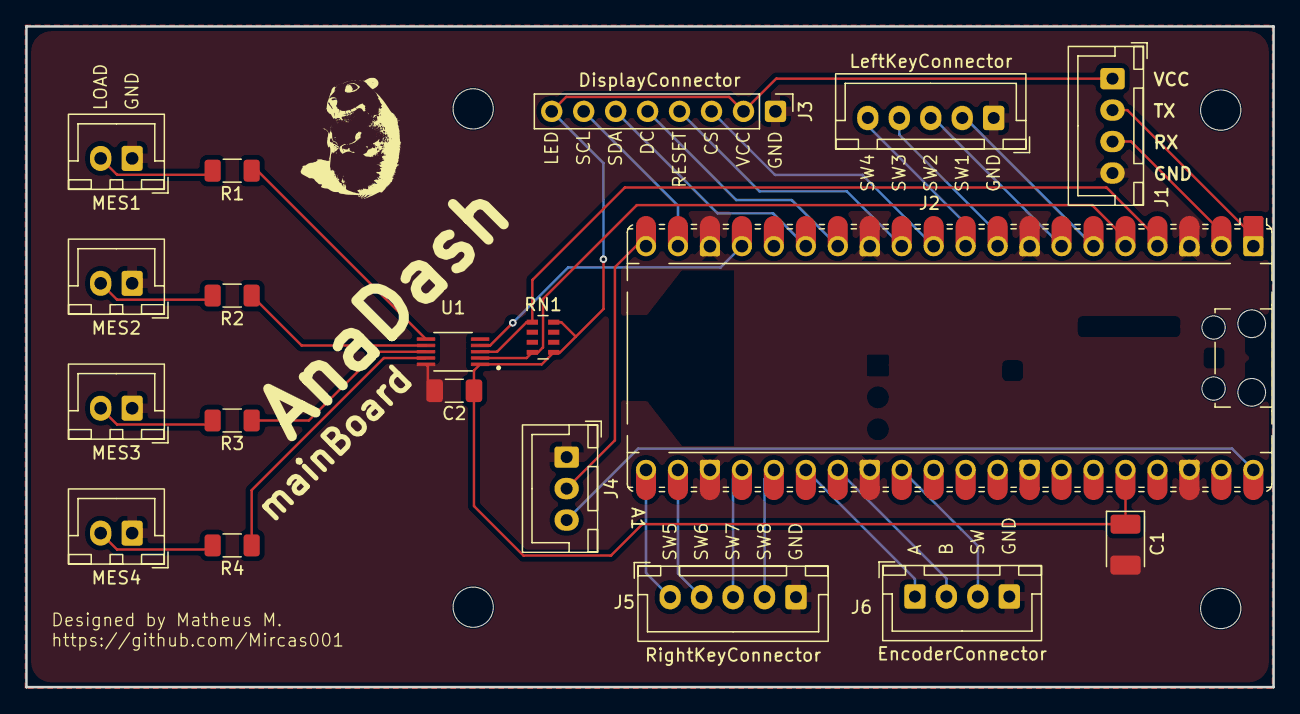
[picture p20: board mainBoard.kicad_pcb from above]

Board: 2 copper layers, 99.1 x 52.5 mm, 19 parts (0 on the bottom side), 33 nets.

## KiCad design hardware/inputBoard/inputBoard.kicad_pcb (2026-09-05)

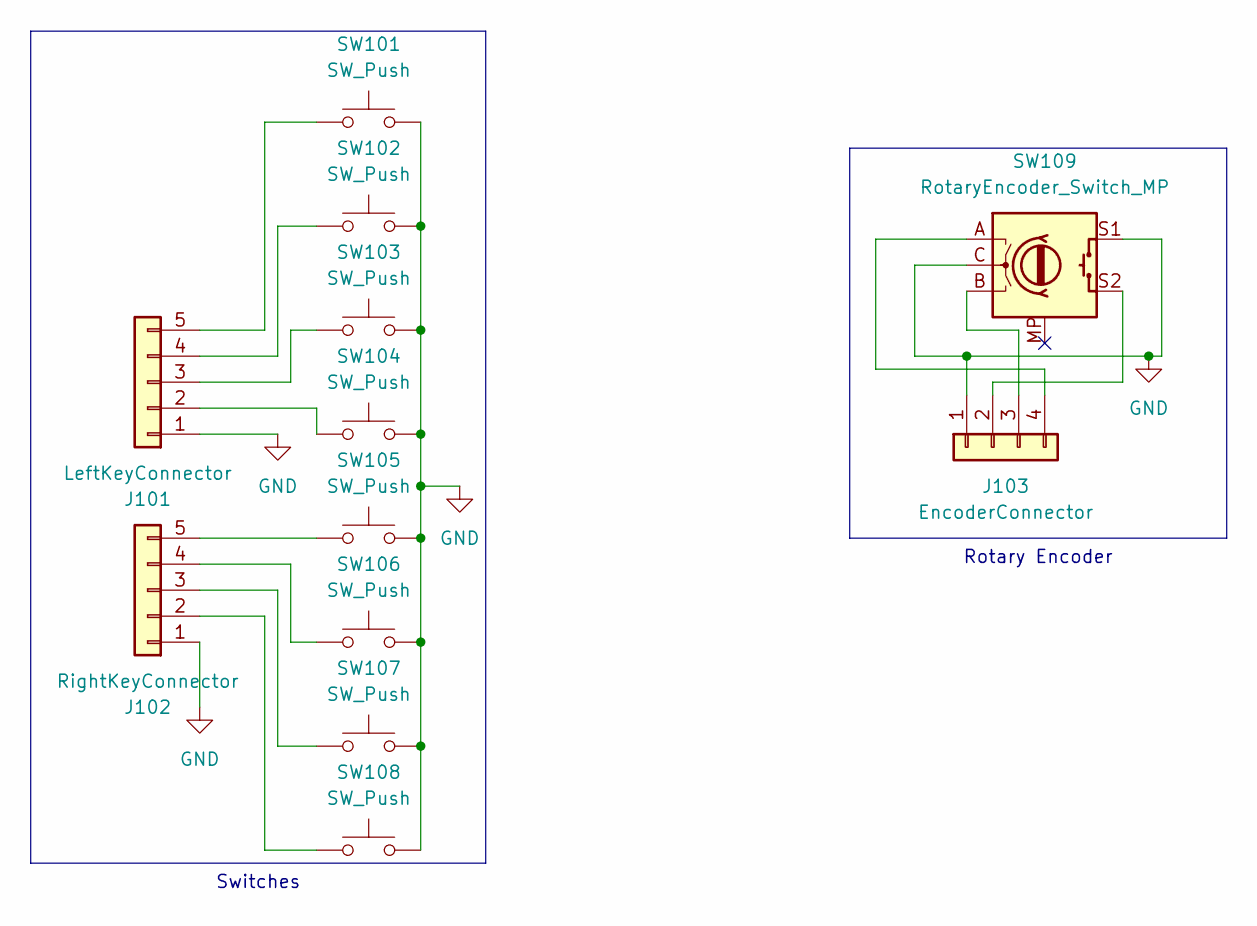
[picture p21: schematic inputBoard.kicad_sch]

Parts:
J101: LeftKeyConnector; JST_XH_B5B-XH-A_1x05_P2.50mm_Vertical; LCSC Part # C157991
J102: RightKeyConnector; JST_XH_B5B-XH-A_1x05_P2.50mm_Vertical; LCSC Part # C157991
J103: EncoderConnector; JST_XH_B4B-XH-A_1x04_P2.50mm_Vertical; LCSC Part # C144395
SW101, SW102, SW103, SW104, SW105, SW106, SW107, SW108: SW_Push; SW_Cherry_MX_1.00u_PCB; LCSC Part # N/A
SW109: RotaryEncoder_Switch_MP; RotaryEncoder_Alps_EC11E-Switch_Vertical_H20mm; LCSC Part # C370986

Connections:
GND: J101.1, J102.1, J103.1, SW101.2, SW102.2, SW103.2, SW104.2, SW105.2, SW106.2, SW107.2, SW108.2, SW109.C, SW109.S1
unnamed: J101.2, SW104.1
unnamed: J101.3, SW103.1
unnamed: J101.4, SW102.1
unnamed: J101.5, SW101.1
unnamed: J102.2, SW108.1
unnamed: J102.3, SW107.1
unnamed: J102.4, SW106.1
unnamed: J102.5, SW105.1
unnamed: J103.2, SW109.S2
unnamed: J103.3, SW109.B
unnamed: J103.4, SW109.A

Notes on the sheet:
Switches
Rotary Encoder

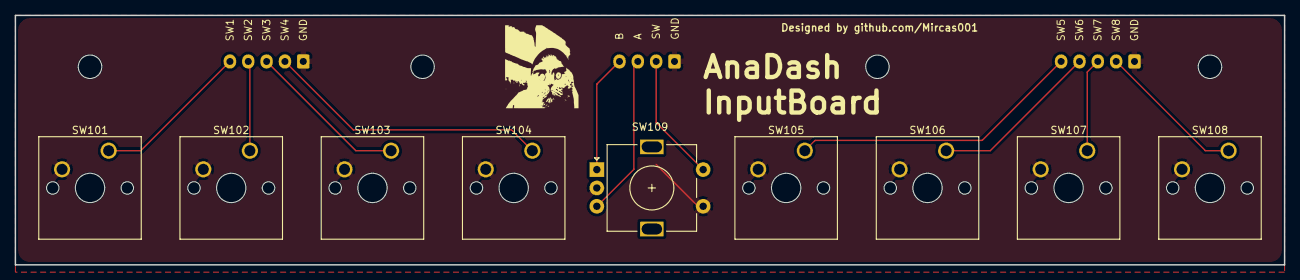
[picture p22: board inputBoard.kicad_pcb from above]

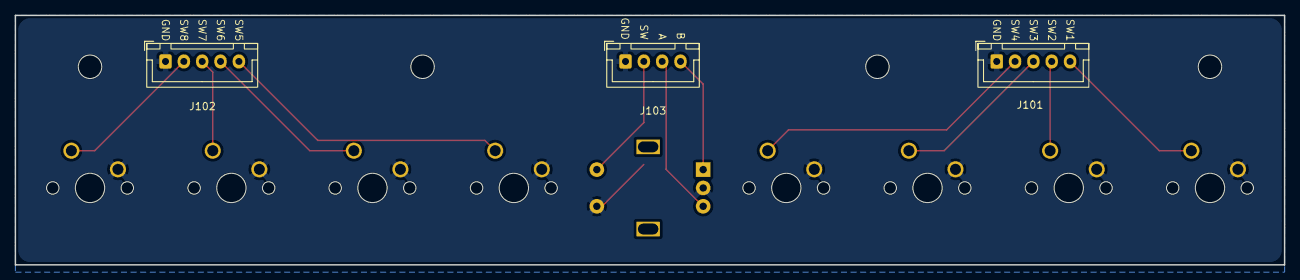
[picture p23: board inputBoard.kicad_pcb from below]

Board: 2 copper layers, 173.0 x 34.0 mm, 12 parts (3 on the bottom side), 12 nets.

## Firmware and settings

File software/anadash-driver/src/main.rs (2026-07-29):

use anyhow::Result;
use log::info;
use shared::{DashboardData, HostTransmission};
use std::io::Write;
use tokio::time::{Duration, interval};
use tokio_serial::SerialPortBuilderExt;

mod hardware_info;
mod mpris_monitor;
mod notification_monitor;
mod tests;
mod utils;

#[tokio::main]
async fn main() -> Result<()> {
    env_logger::init();
    info!("Starting driver...");
    #[cfg(not(target_family = "unix"))]
    compile_error!("Only unix systems are supported!");

    #[cfg(not(target_os = "linux"))]
    warn!("A non-linux Unix system has been detected, this might not work!");

    info!("Opening serial port");
    let serial_path = std::env::args()
        .nth(1)
        .expect("You shouldn't be running this manually! use: anadash-driver <device>"); // * we know it's someone running it manually because they screwed up the port
    let mut keyboard_cdc = match tokio_serial::new(serial_path, 115200).open_native_async() {
        Ok(port) => port,
        Err(e) => panic!("Error opening serial port! {}", e), // * seriously, I know good rust programs don't panic, but this is the whole core functionality
    };

    info!("Getting hardware info object");
    let mut hwinfo: hardware_info::HardwareInfo = hardware_info::HardwareInfo::new();

    info!("Starting DBUS monitor");
    // naming it notificationsYapper would be unprofessional :(
    let mut notifications_rx = notification_monitor::spawn_notification_monitor();

    info!("Starting MPRIS monitor");
    let mut mpris_player = mpris_monitor::MprisPlayer::new();

    let mut timer: tokio::time::Interval = interval(Duration::from_secs(1));

    loop {
        // this will send the current time every second to the resource monitor
        tokio::select! {
            Some(noti) = notifications_rx.recv() => {
                info!("Notification received!");
                let mut buf = [0u8; 256];
                let bytes = postcard::to_slice_cobs(&noti, &mut buf)?; // * nice format to send over data 
                keyboard_cdc.write_all(bytes)?;
            }
            _ = tokio::signal::ctrl_c() => {
                println!("Goodbye ;)");
                break;
            }
            _ = timer.tick() => {
                info!("Getting hardware info");
                let hw_stats = hwinfo.get_data();
                info!("Getting MPRIS..."); // * i hope those infos don't take too much time.
                mpris_player.update();

                let data  = HostTransmission::Dashboard(DashboardData {
                    time: utils::live_clock(),
                    mem_used: hw_stats.mem_used,
                    swap_used: hw_stats.swap_used,
                    cpu_load: hw_stats.cpu_load,
                    cpu_temp: hw_stats.cpu_temp,
                    player_status: mpris_player.status,
                    artist: heapless::String::try_from(mpris_player.artist.as_str()).unwrap_or_default(),
                    title: heapless::String::try_from(mpris_player.title.as_str()).unwrap_or_default(),
                    progress: mpris_player.progress,
                    duration: mpris_player.duration,
                });
                info!("Sending data over..");
                let mut buf = [0u8; 256];
                let bytes = postcard::to_slice_cobs(&data, &mut buf)?;
                keyboard_cdc.write_all(bytes)?;
            }
        }
    }

    Ok(())
}

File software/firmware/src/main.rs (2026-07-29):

#![no_std]
#![no_main]

use core::error;

use crate::usb_handler::CDC_CHANNEL;
use defmt::*;
use embassy_executor::Spawner;
use embassy_rp::bind_interrupts;
use embassy_rp::i2c::InterruptHandler as i2cIrqs;
use embassy_rp::peripherals::{I2C1, UART0, USB};
use embassy_rp::uart::InterruptHandler as UARTInterruptHandler;
use embassy_rp::usb::InterruptHandler as UsbIrqs;
use embassy_time::Delay;
use embedded_hal_bus::spi::ExclusiveDevice;
use mcp4728::MCP4728Async;
use shared::HostTransmission;
use static_cell::StaticCell;
use {defmt as _, panic_probe as _};

mod display;
mod hardware;
mod usb_handler;

bind_interrupts!(struct Irqs {
    USBCTRL_IRQ => UsbIrqs<USB>;
    I2C1_IRQ => i2cIrqs<I2C1>;
    UART0_IRQ => UARTInterruptHandler<UART0>;
});

static SERIAL: StaticCell<embassy_rp::uart::Uart<'static, embassy_rp::uart::Blocking>> =
    StaticCell::new();

#[embassy_executor::main]
async fn main(_spawner: Spawner) {
    let mut hardware = hardware::Hardware::default();

    let uart = SERIAL.init(hardware.uart);

    defmt_serial::defmt_serial(uart);

    info!("Hello!");

    let mut meters = MCP4728Async::new(&mut hardware.i2c, 0x60);
    if let Err(e) = meters.fast_write(4096, 4096, 4096, 4096).await {
        warn!("Failed to write to meters! {}", e);
    }
    hardware.ldac.set_high();

    usb_handler::begin_usb_handler(&_spawner, hardware.usb, hardware.inputs);

    hardware.ldac.set_low();

    let display_spi = ExclusiveDevice::new(hardware.spi, hardware.cs, Delay).unwrap();

    let mut display = display::Display::new(display_spi, hardware.rst, hardware.dc);

    loop {
        let incoming_data = CDC_CHANNEL.receive().await;
        match incoming_data {
            HostTransmission::Notification(noti) => {
                display.show_notification(noti);
            }
            HostTransmission::Dashboard(dash) => {
                if let Err(e) = meters
                    .fast_write(dash.cpu_load, dash.cpu_temp, dash.mem_used, dash.swap_used)
                    .await
                {
                    warn!("Failed to write to meters! {}", e);
                }
                hardware.ldac.set_high();
                display.update_screen(dash);
            }
        }
    }
}

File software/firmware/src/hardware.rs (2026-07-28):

use crate::Irqs;
use defmt::*;
use embassy_rp::gpio::{Input, Level, Output, Pull};
use embassy_rp::i2c::{self, Config as I2cConfig};
use embassy_rp::peripherals::{I2C1, SPI1, USB};
use embassy_rp::spi::{Blocking as BlockingSpi, Config as SpiConfig, Spi};
use embassy_rp::uart::{Config as UartConfig, Uart};

pub mod input_handler;

pub struct Hardware {
    pub uart: Uart<'static, embassy_rp::uart::Blocking>,
    pub usb: embassy_rp::Peri<'static, USB>,
    pub inputs: input_handler::KeyInputs<'static>,
    pub i2c: i2c::I2c<'static, I2C1, i2c::Async>,
    pub ldac: Output<'static>,
    pub cs: Output<'static>,
    pub rst: Output<'static>,
    pub dc: Output<'static>,
    pub spi: Spi<'static, SPI1, BlockingSpi>,
}

impl Default for Hardware {
    fn default() -> Self {
        let p = embassy_rp::init(Default::default());

        let uart = Uart::new_blocking(p.UART0, p.PIN_0, p.PIN_1, UartConfig::default());

        info!("Starting hardware!");

        let usb = p.USB;

        let sda = p.PIN_2;
        let scl = p.PIN_3;
        let i2c = i2c::I2c::new_async(p.I2C1, scl, sda, Irqs, I2cConfig::default());
        let ldac = Output::new(p.PIN_13, Level::Low);

        let spi = Spi::new_blocking(p.SPI1, p.PIN_14, p.PIN_11, p.PIN_12, SpiConfig::default());
        let cs = Output::new(p.PIN_8, Level::Low);
        let rst = Output::new(p.PIN_9, Level::Low);
        let dc = Output::new(p.PIN_10, Level::Low);

        let enc_a = Input::new(p.PIN_20, Pull::Up);
        let enc_b = Input::new(p.PIN_21, Pull::Up);

        let key_inputs = input_handler::KeyInputs::new(
            Input::new(p.PIN_4, Pull::Up),
            Input::new(p.PIN_5, Pull::Up),
            Input::new(p.PIN_6, Pull::Up),
            Input::new(p.PIN_7, Pull::Up),
            Input::new(p.PIN_16, Pull::Up),
            Input::new(p.PIN_17, Pull::Up),
            Input::new(p.PIN_18, Pull::Up),
            Input::new(p.PIN_19, Pull::Up),
            enc_a,
            enc_b,
            Input::new(p.PIN_22, Pull::Up),
        );
        Self {
            uart: uart,
            usb: usb,
            inputs: key_inputs,
            i2c: i2c,
            ldac: ldac,
            cs: cs,
            rst: rst,
            dc: dc,
            spi: spi,
        }
    }
}

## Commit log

2026-06-27 Drawed up the DAC n meters
    [anadash_pcb.kicad_pcb, anadash_pcb.kicad_sch]
2026-06-28 Finish up the schematic
    [anadash_pcb.kicad_sch]
2026-07-03 esp32 switch :d
    Something something
    [anadash_pcb.kicad_sch]
2026-07-03 Revert "esp32 switch :d"
    This reverts commit a7c39a4a50a5a8529a2412f65cccd0cacde0d017.
    [anadash_pcb.kicad_sch]
2026-07-03 Added test pads, change the switches's wiring, added an encoder
    [anadash_pcb.kicad_sch]
2026-07-03 pcb design
    [anadash_pcb.kicad_pcb, anadash_pcb.kicad_sch]
2026-07-03 fresh start to pcb
    [anadash_pcb.kicad_pcb, anadash_pcb.kicad_sch]
2026-07-03 Make the schematics pretty, no PCB tho
    [anadash_pcb.kicad_sch, switchesanddisplay.kicad_sch]
2026-07-03 Finish the schematic ig
    [anadash_pcb.kicad_sch, switchesanddisplay.kicad_sch]
2026-07-03 Ground should point downwards so i fixed that
    [anadash_pcb.kicad_sch, switchesanddisplay.kicad_sch]
2026-07-03 Wire up the schematic for the switches
    [anadash_pcb.kicad_sch, switchesanddisplay.kicad_sch]
2026-07-03 Fix the 46 ERC rules
    [anadash_pcb.kicad_sch, switchesanddisplay.kicad_sch]
2026-07-03 Okay, NOW I fixed the 46 ERC rules
    [anadash_pcb.kicad_sch, switchesanddisplay.kicad_sch]
2026-07-03 Reorganizing into two different projects
    Kicad doenst allow two PCBs
    [anadashMainBoard.kicad_pcb, anadashMainBoard.kicad_sch, anadashSecondaryBoard.kicad_pcb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]
2026-07-03 Laid out the components
    [anadashMainBoard.kicad_pcb]
2026-07-03 Made the mainboard PCB
    [anadashMainBoard.kicad_pcb]
2026-07-03 Improve the mainboard pcb's 3d model
    [anadashMainBoard.kicad_pcb]
2026-07-03 Fix the Z positioning of the dac module in the 3d model
    [anadashMainBoard.kicad_pcb]
2026-07-03 Finish the mainboard PCB
    [anadashMainBoard.kicad_pcb]
2026-07-03 Add Main Board PCB assets, and add BOM
    [mainBoardBOM.csv]
2026-07-03 Update CSV
    [finalBOM.csv]
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2026-07-03 Finish the 2nd PCB
    [anadashSecondaryBoard.kicad_pcb, anadashSecondaryBoard.kicad_sch]
2026-07-05 remove this CSV
    [mainBoardBOM.csv]
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2026-07-05 Fixing alignment, improvements to pcb such as silkscreen.
    [anadashMainBoard.kicad_pcb, anadashMainBoard.kicad_sch, anadashSecondaryBoard.kicad_pcb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]
2026-07-05 both pcbs are done, but readme is bad
    [anadashSecondaryBoard.kicad_pcb, anadashSecondaryBoard.kicad_sch]
2026-07-08 change to thermal relief pads
    [anadashMainBoard.kicad_pcb, anadashSecondaryBoard.kicad_pcb]
2026-07-08 added 3d files, or so I hopew
    [anadashMainBoard.kicad_pcb]
2026-07-08 fix the naming on one of the PCB assets
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2026-07-08 fix silkscreen on the mainboard
    [anadashMainBoard.kicad_pcb]
2026-07-08 Fix wrong pinout order, and wrong GND shape
    [anadashMainBoard.kicad_pcb, anadashMainBoard.kicad_sch]
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2026-07-09 the drivers were plural for some reason, that was fixed
    [main.rs]
2026-07-09 Barebones driver giving CPU, RAM and SWAP
    [main.rs]
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2026-07-09 Atualizar o finalBOM.csv
    [finalBOM.csv]
2026-07-09 remove tracking link on finalbon
    [finalBOM.csv]
2026-07-09 fix messed up CSV in finalbom
    [finalBOM.csv]
2026-07-09 fix another mistake in the bom
    [finalBOM.csv]
2026-07-09 okay, final mistake in the csv corrected
    [finalBOM.csv]
2026-07-10 removed assets, added mounting holes, made the aux pcb smaller
    [anadashSecondaryBoard.kicad_pcb]
2026-07-10 update bom cuz i changed the display
    [finalBOM.csv]
2026-07-10 fix mandatory formatting issue
    [finalBOM.csv]
2026-07-10 fix comma being used instead of dot
    [finalBOM.csv]
2026-07-10 fix final price
    [finalBOM.csv]
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2026-07-11 Added folk valley cat and hamster to the PCB
    [anadashMainBoard.kicad_pcb, anadashMainBoard.kicad_sch, anadashSecondaryBoard.kicad_pcb]
2026-07-11 reorganize assets, update BOM
    [finalBOM.csv]
2026-07-11 reorganizing the file structure + readme
    [finalBOM.csv, inputBoard.kicad_pcb, inputBoard.kicad_sch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]
2026-07-11 Update inputboard to have keycaps on the 3d model
    [inputBoard.kicad_pcb]
2026-07-13 Switched from prebuilt module to chip
    [mainBoard.kicad_pcb, mainBoard.kicad_sch]
2026-07-13 update README.md to have kicanvas and 3d model image, also fix main board PCB
    [mainBoard.kicad_pcb]
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2026-07-14 Label the connectors in the silkscreen
    [inputBoard.kicad_pcb, inputBoard.kicad_sch, mainBoard.kicad_pcb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]
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2026-07-21 Encoder working, and warnings fixed
    [hardware.rs, input_task.rs, main.rs]
2026-07-22 update PCB routing and add debug probe
    [inputBoard.kicad_pcb, inputBoard.kicad_sch, mainBoard.kicad_pcb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]
2026-07-23 replace LCD 3d model
    [1e77-TFT-160x128.stp]
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2026-07-25 update wiring
    [mainBoard.kicad_pcb, mainBoard.kicad_sch]
2026-07-26 fix bogus wiring
    [mainBoard.kicad_sch]
2026-07-26 update wrong ldac pin
    [mainBoard.kicad_pcb, mainBoard.kicad_sch]
2026-07-26 fix wrong wire positioning
    [mainBoard.kicad_sch]
2026-07-27 add update_screen, fix main
    [display.rs, main.rs]
2026-07-27 avoid unnecessary panics in display
    [display.rs]
2026-07-27 fixed up the embedded-icon situation
    [display.rs]
2026-07-27 update driver name to avoid conflict
    [main.rs]
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2026-07-28 add led headers to main board
    [mainBoard.kicad_pcb, mainBoard.kicad_sch]
2026-07-28 add led header to pcb
    [mainBoard.kicad_pcb, mainBoard.kicad_sch]
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2026-07-28 add gerbers
    [inputBoard-B_Cu.gbr, inputBoard-B_Mask.gbr, inputBoard-B_Paste.gbr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]
2026-07-28 add BOM
    [BOM.csv]
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2026-07-28 ompress the gerbers
    [inputBoard-B_Cu.gbr, inputBoard-B_Mask.gbr, inputBoard-B_Paste.gbr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]
2026-07-28 update mainboard to use resistor array
    [mainBoard.kicad_pcb, mainBoard.kicad_sch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]
2026-07-28 add production files
    [BOM.csv, bom.csv, designators.csv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]
2026-07-28 update production files + start miscellaneous bom
    [MiscBOM.csv, inputBoard.kicad_sch]
2026-07-29 revert main from before led
    [main.rs]
2026-07-30 add miscellaneous BOM
    [MiscBOM.csv]
2026-07-30 update BOM to change capacitor + new gerbers + update the production files
    [MiscBOM.csv, bom.csv, mainBoard.kicad_pcb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]
2026-07-30 update silkscreen positioning
    [mainBoard.kicad_pcb]
2026-07-30 update resistor size
    [bom.csv, inputBoard.kicad_pcb, mainBoard.kicad_pcb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]
2026-07-30 UPDATE bom
    [BOM.csv, MiscBOM.csv]
2026-07-30 update broken links, update bom name, remove useless bom
    [bom.csv, jlcpcb_bom.csv]
2026-07-31 update inputboard to use one layer only
    [inputBoard.kicad_pcb]
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2026-08-01 add meter label assets, adjustments
    [inputBoard.kicad_pcb, mainBoard.kicad_pcb, mainBoard.kicad_sch]
2026-08-01 update production files
    [inputBoard.kicad_pcb]
2026-08-11 add assembly, update BOM
    [BOM.csv]
2026-08-12 fix formatting mistake
    [BOM.csv]
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2026-08-13 upload printables
    [anaDash Printables - leftCase.stl, anaDash Printables - leftFront.stl, anaDash Printables - leftPlate.stl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]
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2026-08-19 add schematic to readme
    [inputBoard.kicad_sch]
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2026-08-19 invert schematic colors
2026-09-04 update inputboard
    [bom.csv, designators.csv, inputBoard.kicad_pcb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]
2026-09-05 update inputboard alignment
    [inputBoard.kicad_pcb, inputBoard.step, mainBoard.step]
2026-09-05 update design
    [BOM.csv, anaDash Printables - encoder.step, anaDash Printables - encoder.stl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]
2026-09-05 add models, update silkscreen
    [1e77-TFT-160x128.stp, Analog Current Meter 30mA.step, anaDash Printables - encoder.3mf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]
2026-09-06 final commit
    [BOM.csv]
